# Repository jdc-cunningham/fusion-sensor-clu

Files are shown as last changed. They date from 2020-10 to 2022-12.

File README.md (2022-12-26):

## Update

The second/current version of this approach is [here](https://github.com/jdc-cunningham/pi-zero-2-robot-navigation-head) "Chisel Bot"

## About
This is a piece of crap SLAM from scratch attempt with a Raspberry Pi, camera, ultrasonic/"lidar" sensor on a pan/tilt bed and a 9-axis IMU. Please note I am coming from web-application development so I'm not a SLAM expert or anything, this is just some hobby/fun project for me, don't reference it for anything that matters.

## Completion
- [ ] vision system
  - [x] basics of masking, determining color and light ranges by histograms, determining bounding boxes of largest contour areas
  - [ ] make an algorithm for sampling based on available data ranges and best way to find all objects in an image due to various colors/shapes
  - [ ] get the center of the largest boxes
  - [ ] figure out how to gauge where the object is and then point the sensors at it to get a depth measurement
    - this can be based on camera physical properties but also just sampling with lidar/ultrasonic sensors
- [ ] interface with IMU
  - [ ] connect and get values
  - [ ] estimate position based on rest/accel/velocity
  - [ ] use this to translate points to keep track of where things are
- [ ] add drive servos to body/use external battery separately to drive wheels
- [ ] complete the system where it can be turned on, starts navigating on its own and outputs telemetry to web interface

### Example application
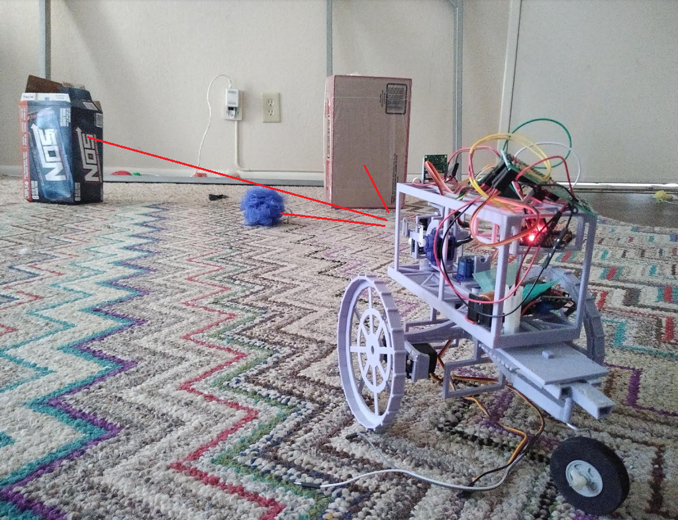
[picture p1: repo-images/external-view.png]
intended vehicle


I am aware that there are methods out there like "visual inertial semantic representation" which are insane! I've seen drone applications with a single camera and it's frame-by-frame attaching dots to things and keeping track of them. No distance measuring like I am. And they pair that with the IMU data to generate depth that's my understanding anyway.

The shot above "why not use an ultrasonic sensor" well they suck on their own. If you're just dealing with perfect walls/no angles then yeah they work great. I'm also aware my approach is probably dumb but this whole project is a learning mechanism for me.

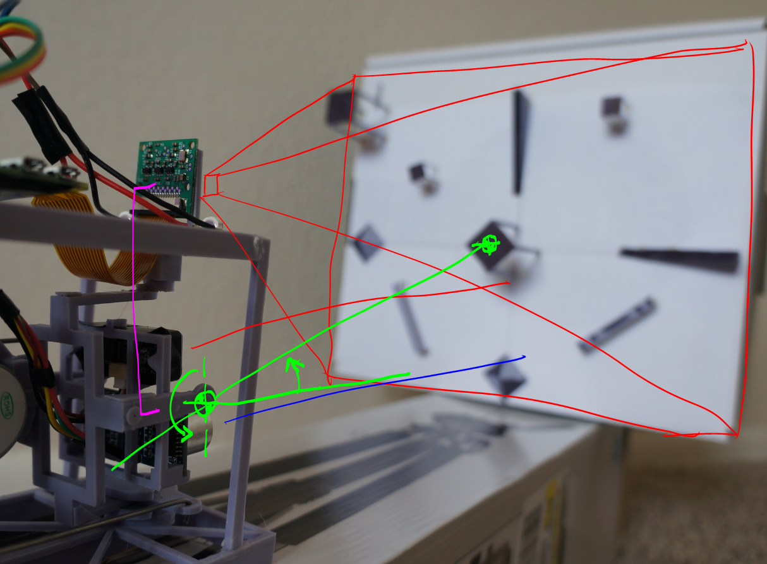
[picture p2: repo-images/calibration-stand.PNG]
initial thoughts


Initially I thought the sensors were way more accurate than they actually are. At the moment I believe the "lidar" at best is for measurements above 2 feet and the ultrasonic sensor is the opposite.

This build is bad in many ways primarily due to the mechanical design/materials and lack of feedback from the pan/tilt sensor bed.

## The stack
- web
  - ReactJS, websocket, ThreeJS
- robot
  - Raspberry Pi
    - NodeJS for server/websocket
    - Python for i2c to Arduino, 3D point cloud/collision
    - OpenCV for visual aspect mainly finding objects, bounding, getting centroid for distance measurement
  - Arduino
    - moves servos for pan tilt by i2c commands
    - moves two 360 deg rotation servos for movement

While I do have a web interface for a visual aspect and manual controls, this robot is intended to operate on its own. The 3D point cloud environment is maintained in memory against the IMU measurements, that's the plan anyway.

### The web interface
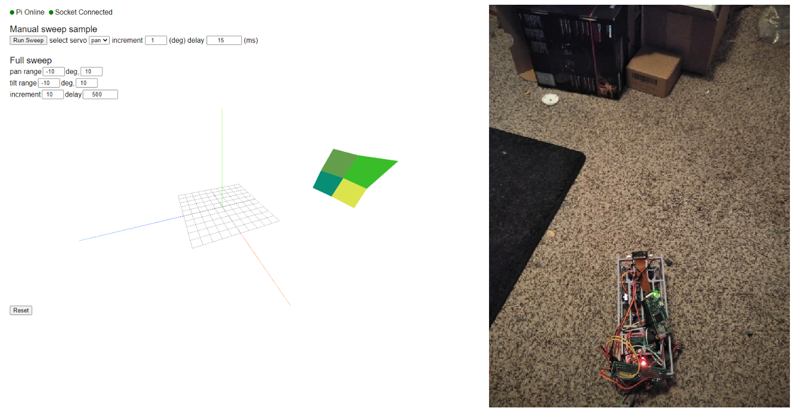
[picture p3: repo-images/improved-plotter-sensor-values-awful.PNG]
showing example 9-point measurement plot


Primarily as mentioned this interface just gives you direct control. Ideally/in the end the ThreeJS part will be almost real time showing the robot's position and the moving environment around it based on what was tracked before. It will all be super dumbed down eg. "everything is a box". One thing I have to figure out as well is mapping the horizon/ground plane.

### The vision aspect

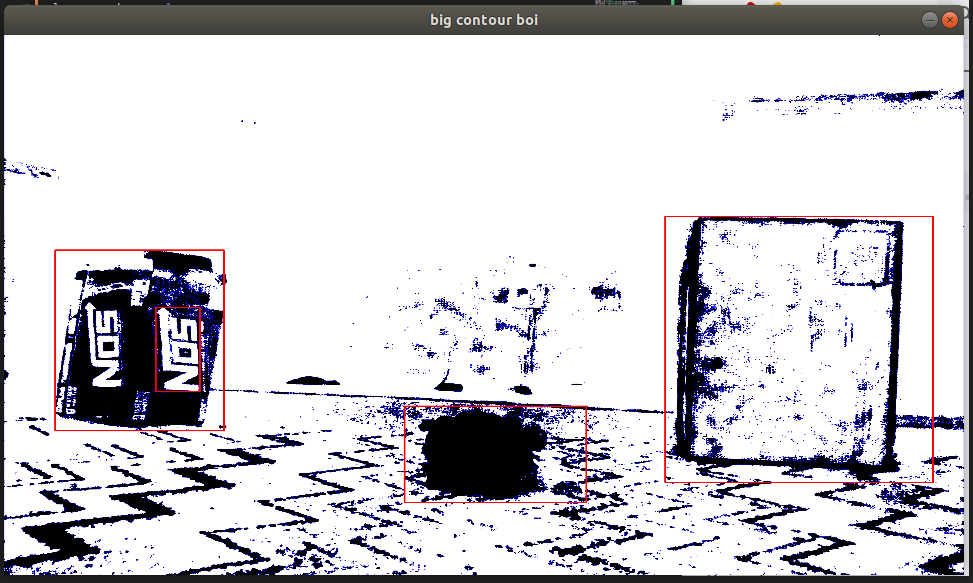
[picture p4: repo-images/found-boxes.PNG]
example masking


This is probably the hardest thing about this project for me followed by the IMU aspect as I have not interfaced with an IMU yet.

The current process is:
* get image
* apply 1D and 2D histograms to get light profile and HS values from image
* use those values for the HSV masks
* find contours by largest area
* get centeroid position of boxes
* determine angles to point sensor bed to get distance
  * maybe involves an initial panning sample with lidar due to angle/fov issue of seen object
* pass these values to the "world coordinate engine" ooh buzzwords

### The maths/IMU
* points are determined for 3D plotting
  * go into ThreeJS for visual
  * go into Python/ram
* IMU values are at center of world, its motions translate the tracked points to simulate reality where objects are/were
* using this and 3D collision detection(box overlap) can tell if you're going to run into something or not
* the known freespace in front determines how far the robot can go before doing something/doing more measurements

### The "main loop"
This is the logic of the robot/why it does what it does. Which is pretty much to keep moving forward if possible. Ultimately the goal of it is to try and map the room. I know I know... just buy a spinning lidar. But That's not the point again not dealing with perfect walls. Also eventually I will take what I've learned here and move onto more powerful boards eg. a Beaglebone or STM32.

### Fantasy/future
* recognition of previously seen objects
  * this one is kind of hard since the objects are all blocks but you could try and average boxes/points and roughly realize these "constellations" haha bs, are some area you've been at before.
* ML for finding the boxes
  * I don't know how feasible, excuse for me to finally try and learn ML for real. I'd have to take so many sample images and annotate them. I had a thought where if the robot fails/runs into something, the last image it has/predictions I could correct(tech parrot).

## Progress

####  11-12-2020
I have written a basic pan/tilt measurement sampling workflow which is then plotted in 3D using ThreeJS. The implementation is basic right now as I have to finish figuring out the math aspect/rendering it correctly.
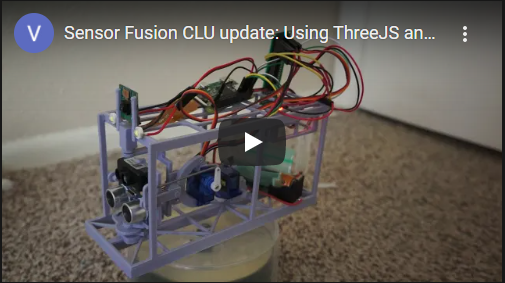
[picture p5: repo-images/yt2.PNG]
youtube video of web interface to threejs (https://www.youtube.com/watch?v=VOdi__m6o3g)


#### 10-28-2020
At this time this project is far from complete. This is also not really meant to be reproduced, it has a lot of flaws.

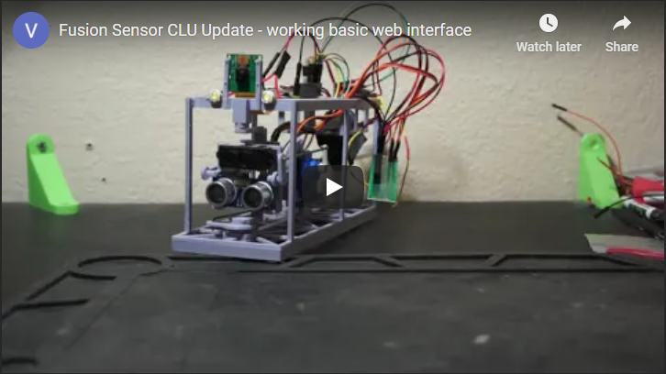
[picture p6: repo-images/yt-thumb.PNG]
youtube video of web interface controlling pan tilt servos (https://www.youtube.com/watch?v=_qi6G4832OI)


It's funny like how much of a piece of crap it looks like and how much work it takes too... printing the top part for example took 7 hrs...

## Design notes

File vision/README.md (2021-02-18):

### About
This is the vision process of this "aparatus". There is a single camera and I'm using 1D and 2D histograms to define the places to look to bind potential objects with HSV. Then using contour finding I find the largest area after a specific minimum area.

It is easier to visually see what I mean by the 1D/2D histograms seeing the images below.

### "The process"

Sorry I'm too lazy to merge these images together right now. This color chart is used as a reference for the purple sample 2D histogram below. I still have to validate manually that this actually works.

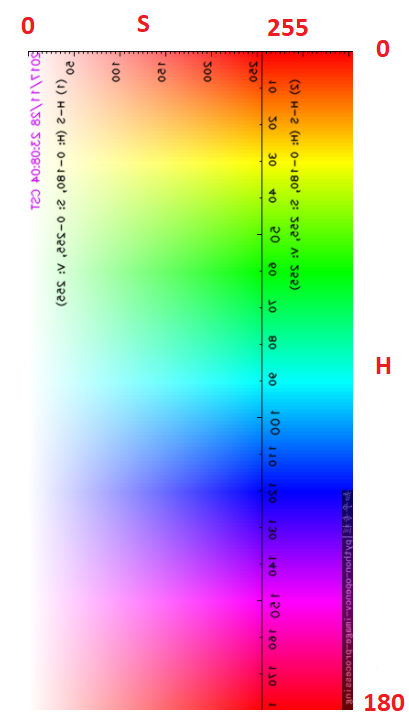
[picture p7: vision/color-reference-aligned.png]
H and S plotted on a chart

This image sourced from here: https://stackoverflow.com/a/48367205/2710227

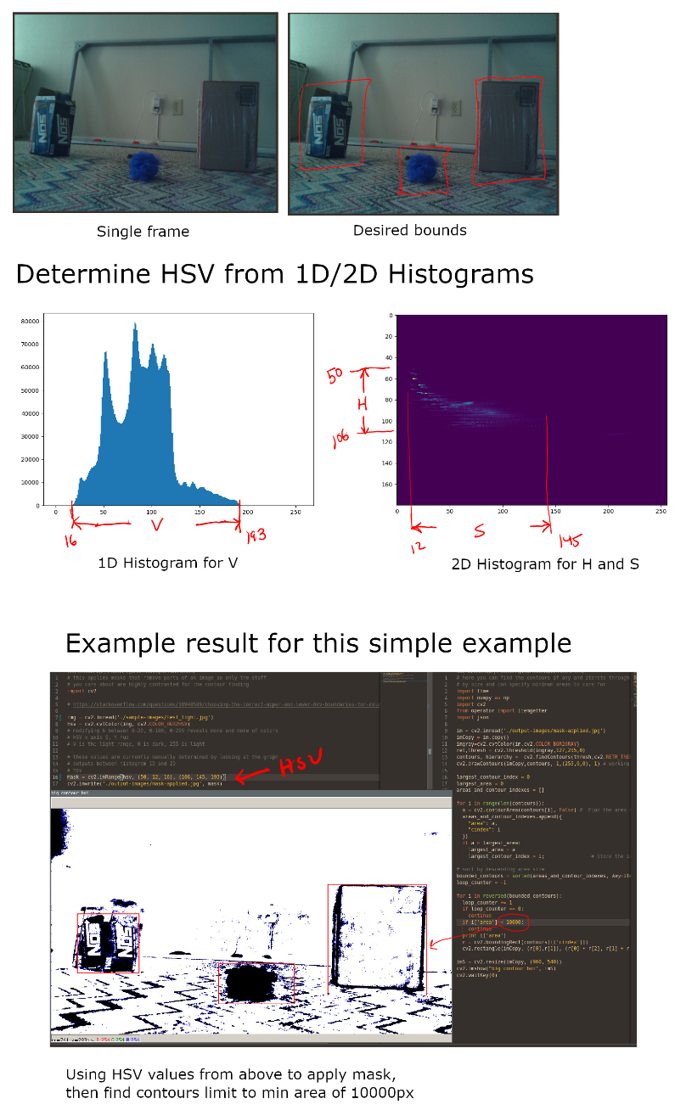
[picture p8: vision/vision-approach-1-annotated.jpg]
vision approach annotated


These bounds are treated as cubes for now/to make it simple. The distances are measured with the ToF sensors and then these values are stored in the "world coordinate system" where the center point(where robot was first turned on) is moved around based on IMU data.

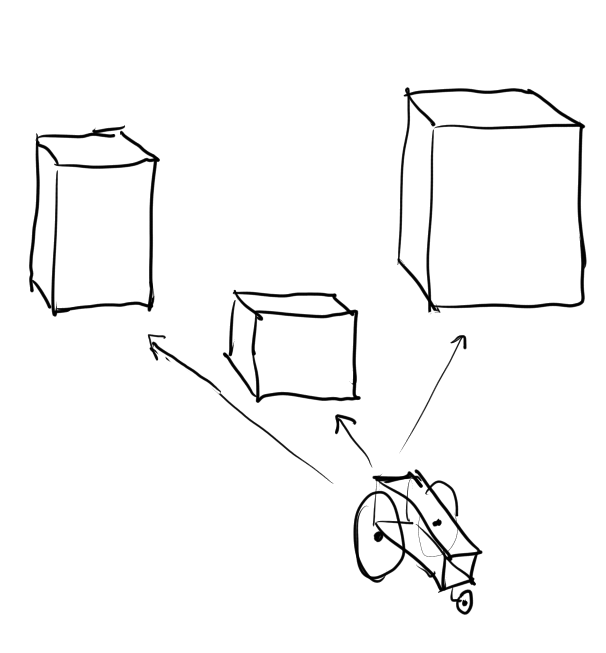
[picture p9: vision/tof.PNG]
approximated 3D objects


I do realize how "lucky"/ideal this simple sample image is. Indeed other images are way harder to draw bounds around, particularly the 2D histogram aspect, that's why I have to step through/sample all the groups. It's also noticeable on the single core Raspberry Pi that can take a process and make it 30 times longer to process due to its processing capability.

### Other notes

Will point out, with the ToF sensors and if it's very dark(V from 1D histogram) can also do preliminary distance sweeps.

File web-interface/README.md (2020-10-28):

# The web interface for the hybrid ground navigation sensor prototype
## This is intended to be used on a touch screen

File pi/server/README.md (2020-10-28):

# the server and socket script should run on boot
## this app uses sysemd based on [Axllent](https://www.axllent.org/docs/nodejs-service-with-systemd/) post

Get both server and socket scripts running so they're visible in process eg. by `htop`

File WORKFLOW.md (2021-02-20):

- [ ] Robot on
- [ ] Turn system logging on(threads/imu)
  - [ ] IMU data sampled by ADC via thread with interrupts
- [ ] Camera takes initial image of environment
  - [ ] OpenCV processing
    - do 2D histogram
    - do contour bounding box and iterate through samples
    - determine box locations
- [ ] do physical samples
  - based on samples above do measurements
  - store/emit
- [ ] Initialize 3D world
  - based on values/points above setup world with robot at center
- [ ] Move/update 3D world
  - do point translation/kinematics/collision detection

end goal is to navigate my entire apartment eg. 5 "rooms" and 1 hallway

### Nice to have features
- [ ] light detection/in relation to 2D HSV histogram
- [ ] basic object recognition after tagging element for updating map "seen it before"
  - particularly since initially will just do lazy approach of "everything is a cube"

### Main tests
- [ ] should be able to tell a wall
  - flat
  - corner
    - away/towards
- [ ] basic boxes
- [ ] complex shapes like a plastic bag

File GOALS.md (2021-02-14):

### These have to be done for it to work
- [ ] Vision
  - [ ] process that can find/draw bounds around everything
  - [ ] ability to target the sensor bed at something and hit it due to the offset from cam/sensor bed center points
- [ ] World coordinate system
  - [ ] store the points
  - [ ] rotate them as the robot moves from IMU data
- [ ] IMU interface
  - [ ] have to get accel, position, rotation, etc... and plug into world coordinate system
  - [ ] determine no longer moving
  - [ ] heading hold regarding servo speed differential
- [ ] Control robot
  - [ ] this should be easy once the above is met, just tells the robot to stop/go/turn

### Future
- [ ] object recognition
  - right now the bounds are basic boxes, but if viewed from other angles should be able to tell it's the same thing seen before

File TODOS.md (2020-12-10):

- ### updates
  - [ ] dpad
    - [ ] add bars/slider
    - [ ] add quick center
    - [x] add setup of major/minor ticks eg. increment by 1 vs. 5
      - only one input but variable
  - [ ] move servo code
    - [ ] add callback when seharvo is done moving, or add matching delay before buttons enabled/able to move again
      - callback from Arduino i2c probably better in case comm delay

- ### reminders
  - socket service user specified is pi to have access to smbus2

- ### "Geometric error"
This is due to the sensors rotating about an offset shared central axis particularly for pitch
Pan has its own problems(since the sensor emit/return are not on the same point/axis)

### Next
- [ ] add background task to Arduino code to unblock itself
- [ ] add reset btn on ui/feed to Arduino
  - happens when some process in Arduino doesn't finish and global variable "something in process"
    left to true
- [x] fix issue with rerender on input after threejs has rendered once
- [x] fix math and update plotting for threejs/add toggles
- [ ] add led lidar
  - test it
  - add as secondary check to confirm measurements
    usensor bad on corners facing away from sensor
- [ ] add method to plot robot as rectangular box in center of ThreeJS plot

### 12/10/2020
Putting a little bit of time in. My brain is not phenomenal I still feel ike a monkey when I can't immediately get some spatial thing. Anyway I took this picture as a reference, shows what the camera can see full resolution. Man idk why this camera sucks but it also wasn't expensive. It's good enough for blob detection.

Also interesting how much of "below the horizon" it sees at the height relative to the floor as a reference

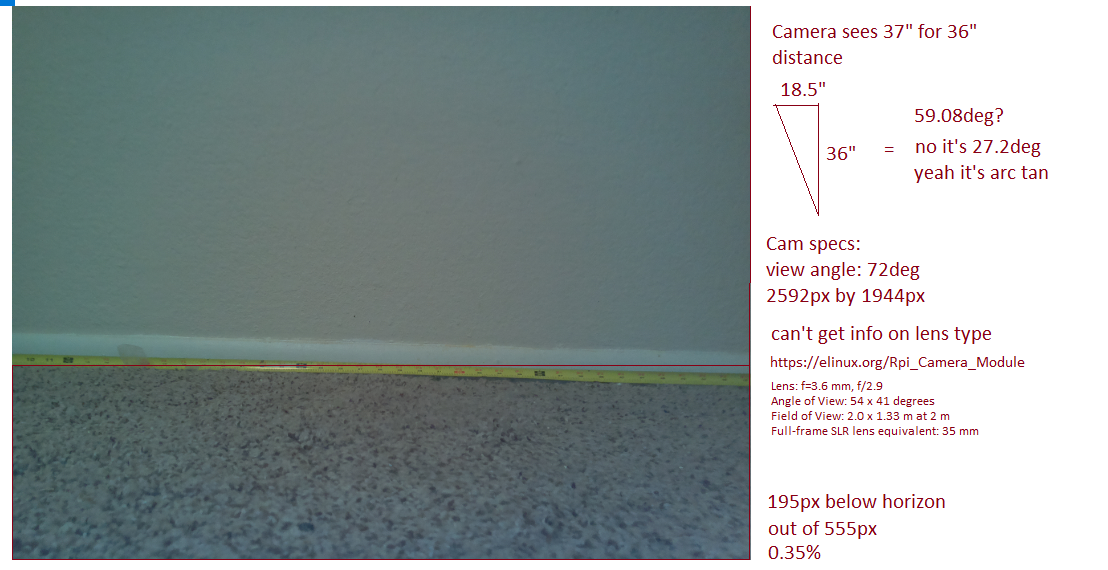
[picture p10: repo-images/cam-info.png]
still don't know


Still don't know yet how to point the sensors at something in picture.
Ugh... my brain sucks. Going to cheat with Sketchup/Cad

For example at 3" the bottom sensor(ultrasonic) has to angle itself 4.5 degrees up to point at the center of the camera frame.

I think aside from general "inference"? Interpretation... idk... I could at the very least do a center sensor sample to get an immediate depth... may suck if something is in front of the object but you could assuming having easy contours use that object as an estimation for everything else based on its bounding box contour size...

There's a relationship though, at least it's a simple right-angle triangle. Half of 36" away it's 9 deg angle up.
The Lidar is a little different, 3.1 deg for 36" and 6.2deg for 18"

Image AR is 1.33 (4/3) or 0.75 (3/4)

Well not scientific at all but can see the camera view angle vs. the sensor angles to point at the same thing due to offset

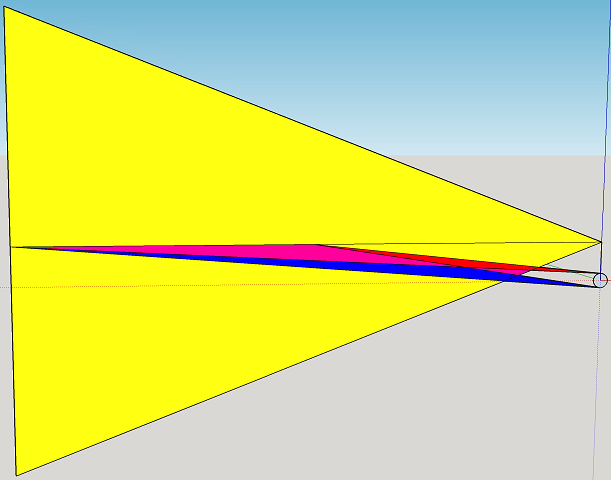
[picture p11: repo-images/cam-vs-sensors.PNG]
sketchup madness


### 12/09/2020
Camera targetting and offset
- [ ] be able to take a picture and based on bounding box/centroid from OpenCV aim lidar/ultrasonic sensor assembly to get distance 
  - example is 4ft foreground(target), everything else is about 7ft away
    - target is 72 square inches

I'm super burnt today, working on this EOD... but today was productive though, a little bit of breathing room.
One of the things I don't understand at the moment is the focal thing of the lens... so if I see something that's 9" across and it is whatever inches on the screen at some pixel... can I roughly know how far awy it is based on that FoV value or whatever.

For now will just work on the basic workflow that will determine the quadrant/point/angles to apply and then use the lidar for the distance ping... if it's closer than the threshold eg. 2' will use ultrasonic for more accurate measurement.

I'm using Gimp to figure out some... well actually paint is fine too. Just need to split the image up into quadarants.

One of the problems is the offset of the camera center with regard to the center of the pan/tilt 

This is the mechanical offset situation... yeah I'm really burnt... can't think anymore. But this is my top priority now personally I want to do a nice writeup/video on this once I have a system that can run on its own.

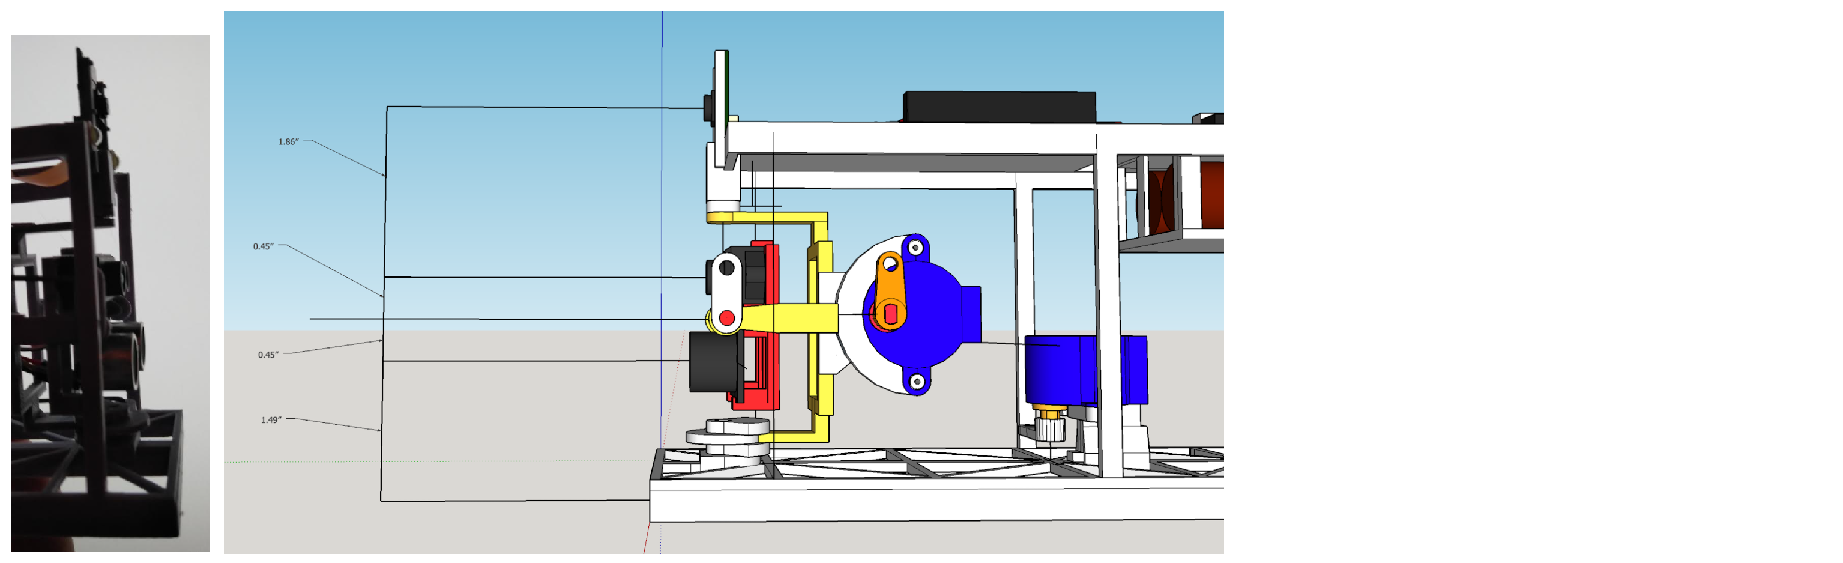
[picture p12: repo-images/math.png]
need to update with math


### 12/08/2020
I did put some time into the panel-splitter-plotter thing(ha). It works now and I added random color to the tiles but the values from the sensor are awful. In particular say facing a corner(with middle closest to cam). It's like measuring infinity or something with the ultrasonic sensor/possibly mismatch of sensor still moving while trying to measure(no feedback).

tears

I did make great progress on the OpenCV part. Some heavy StackOverflowing for that. It's still not written where "it just works" but I have the process down. See this example here where I was able to dynamically figure out the right HSV masks to put bounds around objects in a random picture.

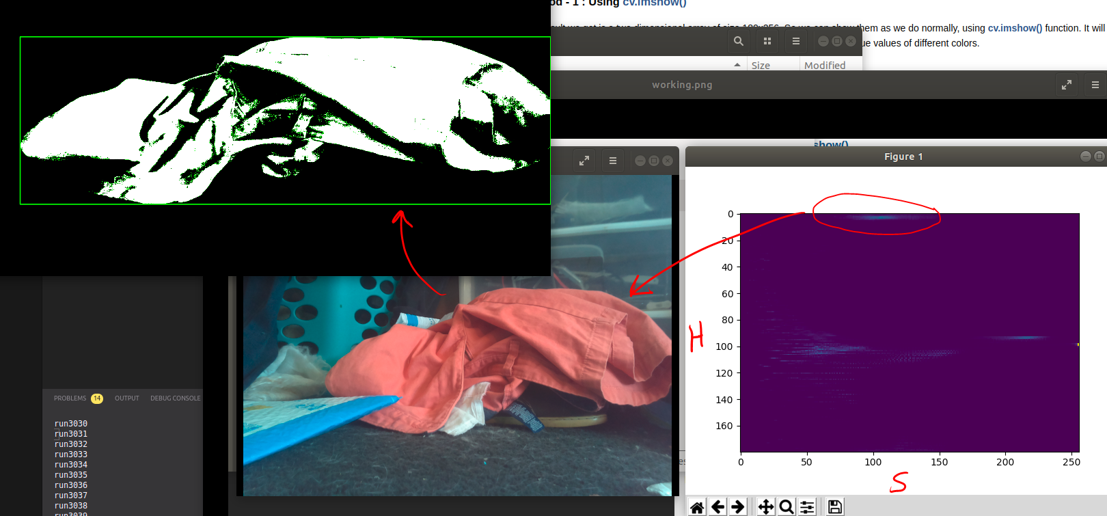
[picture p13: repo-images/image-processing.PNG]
in rain


This project is now top of my list of things to complete though outside of work so I'm hoping to get a write up completed maybe by end of this month December 2020.

I think for the "full workflow prototype" I will just use single-point sampling and treat everything as a box with generous margins of error. Maybe try averaging the "lidar" and ultrasonic sensor measurements.

The IMU aspect is still a big unknown for me at this time.

### 11/26/2020
Well... been busy lately, now have some free time, fresh brain. I had lost interest somewhat, there is still a bit of work to do.

- [x] sweep command stopped working(no change but updated Python cmd string send to Arduino)
  - weird, logged the command ex. `s_p-010,010_t-010,010_i010_500` seems the delay is ignored, sweep sample still works
    not sure if problem is on command part or on Arduino side, no sweep sample is also broken/ignoring the delays
    I will see if reflashing the Arduino code will help(why)
    Oohh look at him, hackerman
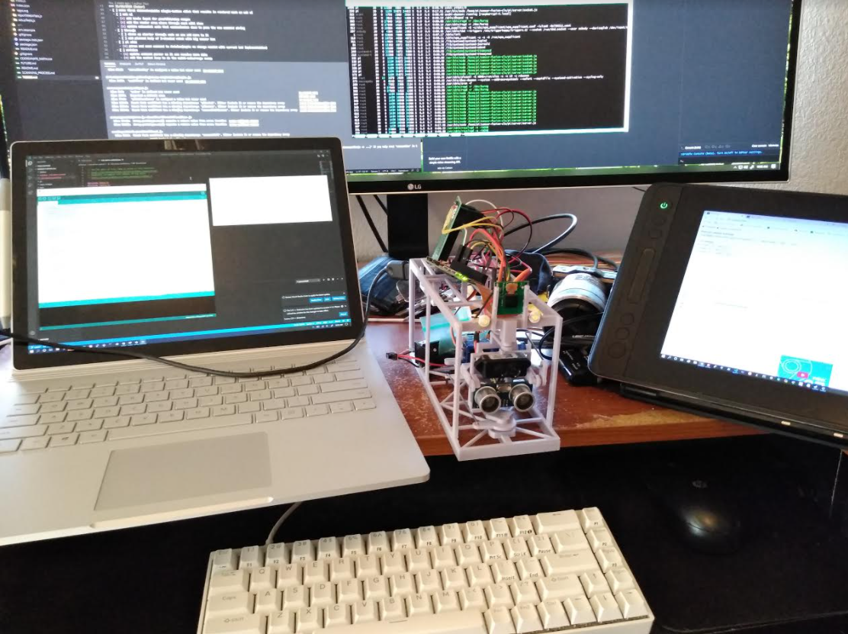
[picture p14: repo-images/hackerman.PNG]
hackerman
    ;
    I do love this giant monitor though, look at me ma! I can SSH
    Anyway I'm adding logging back into the Arduino code to see if it's parsing all the command string characters
    Well it's working again... not sure if the serial print had anything to do with it but the sweep sample while it works has undefined at the end of it... probably a CLI args read issue, but it doesn't seem to affect it so... ugh... I'll fix it. I have to modify either the nodejs code or python code and then reload the systemd service on the Pi.
    Sidenote the Surfacebook is a cumbersome device due to it being top-heavy(tablet is heavier than keyboard). I also have this anxiety about both batteries matching percentages. Still I remember holding one of the first Surface tablets in my hand like 10 years ago... way out of my budget, got this one used. It's cool but I have not really used it yet regarding the tablet aspect.
    so it was literally sending the string "undefined" from node to Arduino... I acknowledge this code is trash
    Anyway I'll remove the serial monitor logs and see if the sweep stuff still works
    One thing I have to do is estimate current consumption, just doing a "started at this voltage, ended with this after x hours", not really sure if that's considered current consumption but I can at least gauge approximate lifespan from 1, 18650 3.4Ah cells.
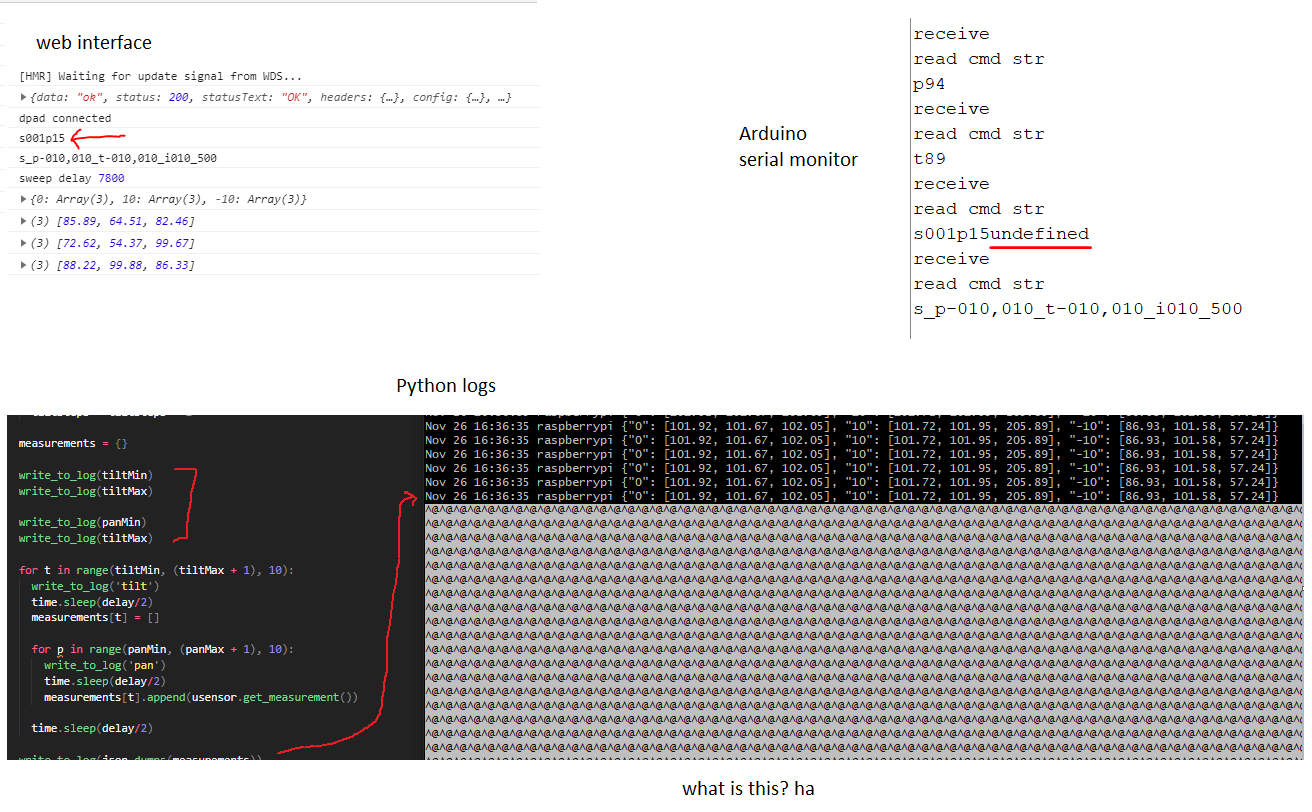
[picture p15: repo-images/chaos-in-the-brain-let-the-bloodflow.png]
madness
    
    sitting "idle"
    3.641V at 11:36 AM
    3.522V at 12:49 PM
    3.301V at 2:13 PM
- [ ] finish function that takes in parameters `(distance, sweep, tilt, increment)` and returns the coordinate pairs for the vertices to make the "plane" or polygon
  - pan pattern starts top left then goes to top-right
  - [when your meager brain cells collect into a pool and somehow establish thought](https://www.youtube.com/watch?v=ZeFonavUHTg)
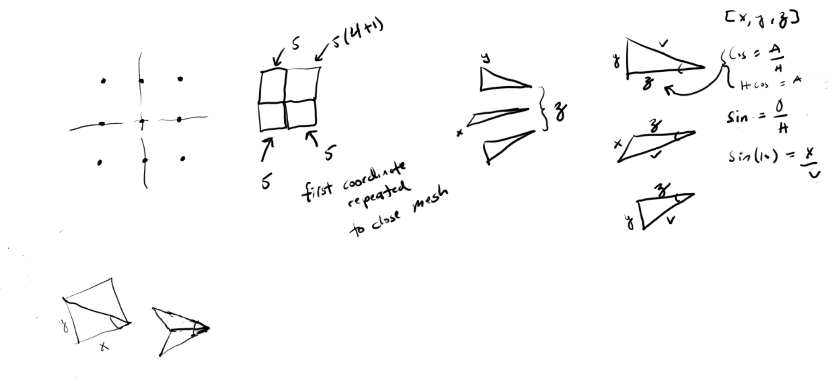
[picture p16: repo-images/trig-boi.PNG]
basic trig
  
  I prototyped out the code to generate the points but  I'm still missing the groupings to generate the mesh/planes
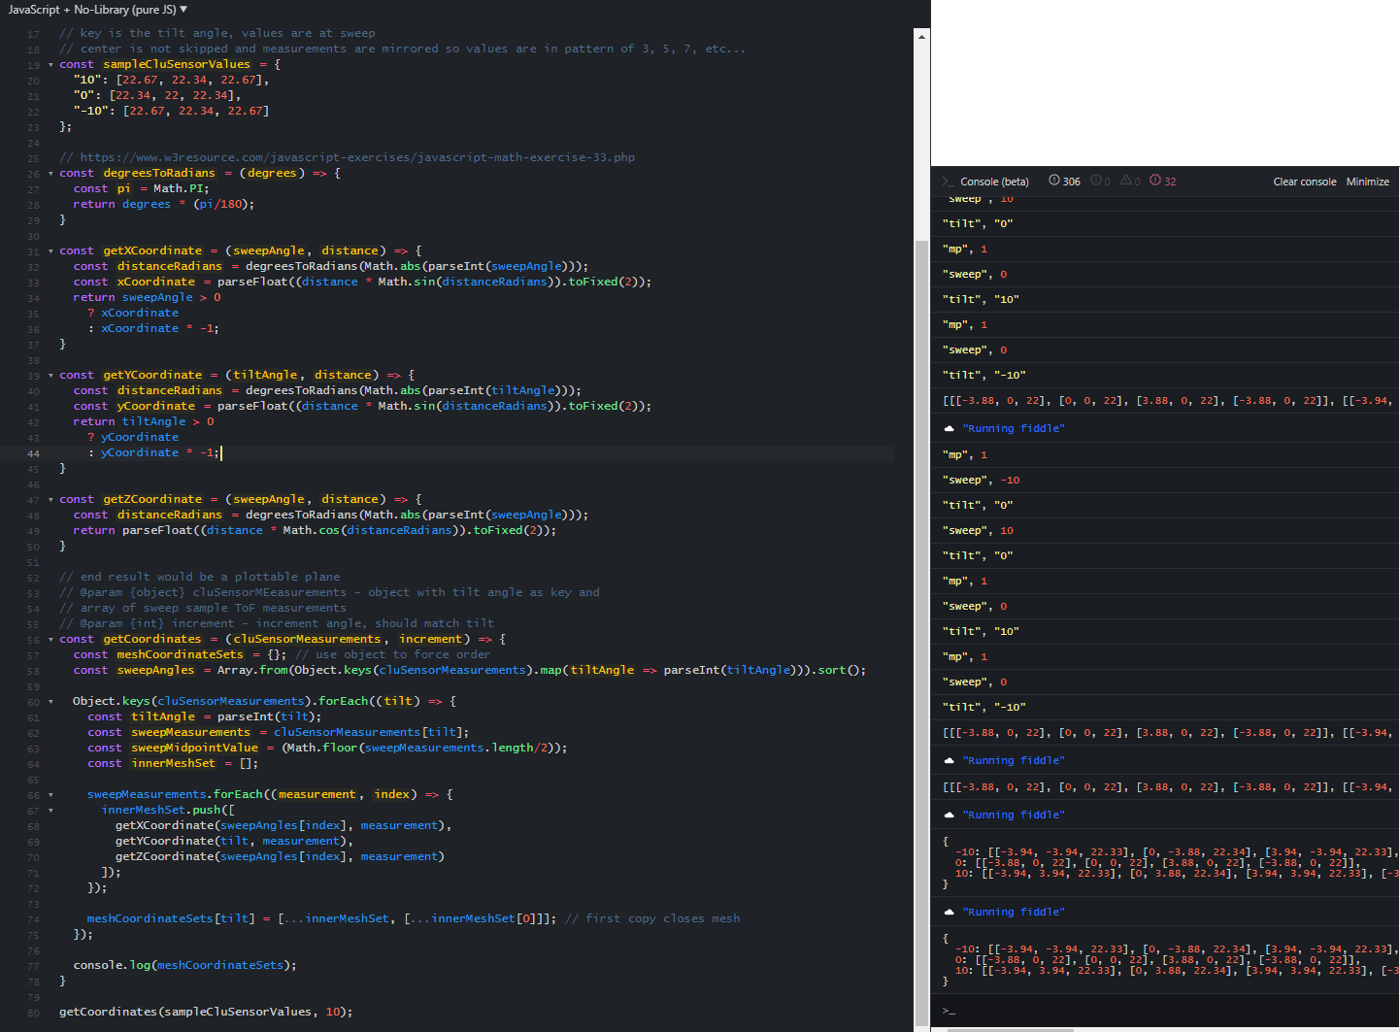
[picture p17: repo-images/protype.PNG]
proto-scopo
  
  seems I have to reset the Arduino if the delays are ignored...
- [ ] start on OpenCV side that scans an image for color groups and then aims the sensor in those directions to get a sample... perhaps can find the corners in a simple case and create approximations(planes) at the appropriate distances
  - so many of the OpenCV tutorials online literally just code out what are in the docs... it's like "we're going to find the red cup" wow! Amazing... every freaking video man.
    it's like, no, I need to be able to find a dynamic range of unknown colors, how do I do that?
    It will be cool when I reach my goal about the "real time running world coordinate system" (bs) regarding the known world position of the robot based on IMU values, stored 3d point objects not only for ThreeJS visual but the mirror that's running in Python for the robot's navigation, ThreeJS is just a human visualization thing.
    I've never built something like this before so it's cool if I get something that remotely works, I realize it's trash and not real time like waving around an iPad in a room to generate a 3D mesh/point cloud collection but still... if it can navigate a robot that's the main goal
- [ ] add "connecting..." ajax spinner to status indicators
- [ ] fix the reset/remove ThreeJS canvas issue

### 11/10/2020 (later)
- [ ] make first demonstratable single-button click that results in rendered mesh on web ui
  - [ ] web ui
    - [x] add basic input for pan/tilt/step ranges
    - [x] add the render area where threejs mesh will show
    - [x] update websocket code that communicates down to pass the new command string
  - [ ] threejs
    - [ ] clean up starter threejs code so can add more to it
    - [ ] add planned body of 2-wheeled robot with big sensor box
  - [ ] pi side
    - [x] parse and send command to Arduino(maybe no change needed with current bad implementation)
  - [ ] arduino
    - [x] update command parser so it can receive more data
    - [x] add the nested loop to do the multi-axis/range sweep

### 11/10/2020
This todo list has become more of an insanity log. An update from before, I initially was trying to learn WebGL but thankfully I found the path of Threejs.
After doing the panic Google session and countless threejs examples/stackoverflow questions I have formulated the basis for the visual rendering.
Earlier(few days back) I wrote the basic math functions to take the measurements coupled with the pan/tilt angles to generate the 3d coordinates... which also need to get cleaned up still.
Anyway I am at the point now where I can make a visual representation of it in 3D to be displayed on the web.
It's not part of the navigational system that will be all in memory but it is a nice-to-have thing. To map the world/gather data and update it based on kinematics(onboard imu).
Mostly I needed a quick burst of "I'm not a failure" even if it's a fantasy/joke what I'm working on.

I'm working with the sample coordinates mentioned below. I still have to investigate why 20+ deg tilt is ignored/cancelled... probably some dumb code in Arduino that I wrote.

I can't spend too much time just wanted to visually display the points below in 3D space using Threejs.

Well... this is not correct at all since I had to throw away a lot of the values and I think the mesh drawer that makes this 3d shape just joins stuff.
If you're looking at this it's not even correct, the point(corner of wall) should face the camera.

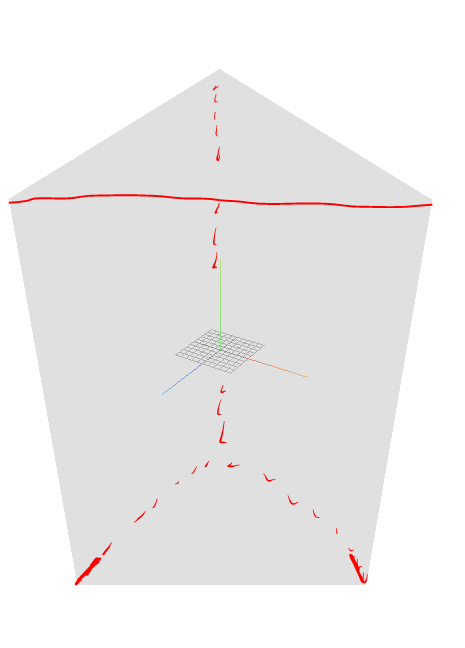
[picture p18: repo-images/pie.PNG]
something


Anyway it's a a start(ain't much meme)

### 11/05/2020
- [x] look into why the angles don't match
  - due to mismatch horn lengths and the horns weren't parallel to each other from the start, only affected pan 
  - updated horn(extended) and updated center points
- [ ] try simpler set of points, see if can plot a plane
- [ ] read through webgl example code
- [ ] full functionality eg. from web command to scan/display webgl "meshes"
  - determine the string command for box scanning
  - do full math
  - add other "callback" part on front end that runs after certain time has passed(dumb) depends on number of points
  - pull the values hosted by pi server
  - plot in webgl
  - then start doing the world mapping
  - add imu
  - add tracking
  - add collision detection
  - add OpenCV blob finding and combine that with above for determining what to scan and plot in world
  - add coordinate find from image and factor in offset based on camera overhead position and pivot point of sensors, general accuracy errors
  - collect data
    - corner wall at 45 degrees, 2ft away
    - us
      - 20 - won't sweep
      - 15 - won't sweep... will have to investigate Arduino code, watch serial
      - 10 - [39.86, 33.91, 34.12, 33.91, 33.87, 34.11, 34.25, 34.59, 34.47, 35.24, 35.68, 39.99, 41.19]
      - 0 - [24.38, 34.18, 33.98, 34.19, 33.99, 34.29, 34.15, 34.35, 34.66, 34.89, 39.42, 39.49, 39.63]
      - 10 - [35.44, 34.29, 34.07, 34.45, 34.08, 34.25, 34.25, 34.35, 34.81, 35.79, 39.71, 40.01, 39.86]
      - 20 - [40.24, 34.72, 34.97, 34.5, 34.84, 34.99, 34.71, 34.82, 35.44, 39.61, 40.73, 40.45, 41.13]
    - lidar - measurement stuck at 65533, not sure if broken or battery
      - it was the battery, after putting in a fresh cell at 4V, was working again, it's bad as I mentioned around 2ft but I measured 38" and it was off by about 0.5"
        vs. 2.5" or so when measuring 18" but received 20.5" as a measurement
      - 20
      - 10
      - 0
      - 10
      - 20

### 11/04/2020
- trying to actually get something done today
- [x] test angles see accuracy and if measurements still work
  - [x] verify angles visually
      - this is not very accurate at all, the accuracy magnitude I had planned initially is way off at least for the "lidar"
  - [x] check measurements from ultrasonic sensor
    - usensor face is 0.5" off (less) from pan/tilt axes, also seems like camera face is 3/8" back from us sensor face
    - yeah this thing is unfortunately f'd since the part where the beam/wave leaves the sensors are not directly in line, there are offsets
      especially when it rotates about the wrong axis
    - rotate 10 deg right, measured 17.73" + 0.5" => 18.51" compared to expected trig value: 18.28" -> 0.23" margin of error
      try again
      10deg -> 18.23" expected, actual is 17.51" + 0.5" -> 18.01" -> 0.22" error
      20deg -> 19.16" expected, actual is 17.72" + 0.5" -> 18.22" -> 1.44" error oof
      30deg -> 20.79" expected, actual is 18.1" + 0.5" -> 18.6" -> 2.19" error ahhh
    - try lidar at 2' -> measures 26.38" -> now bang on at 61cm or 24.02"
      10 deg -> 65.5 cm (avg) -> 66cm
      20 deg -> 66 cm -> 97cm on second measure going backwards
      30 deg -> 78 cm -> 
      ehh... idk... also able to pan farther out than "limits" eg. max of 30 deg in either direction, maybe a good thing (60deg not a big fov for sensors)
    TLDR these measurements suck/not reliable, a panning/general averaging may be passable given enough large margin of errors
    Also sometimes the servos don't move... even when commands are sent, that sucks, concerning
- [x] write first sweep samples
  - ex of 5 deg incr, within 60 deg limit = 12 points -> 6 seconds duration, tested and took about 7.86 seconds to start and stop moving(recenter at end of sweep)
    - as simple baseline can sample at half the speed of delay eg. 500ms = sample every 250ms
    stuck on file writing issue
    - this is not great but I'm just creating a folder with 777 permission, inside that a file with 777 permission
      this code runs by systemd and the user is set to pi, logs confirm as pi but for some reason denied to write to file still when node calls python cli exec cmd
      setting working directory in service that runs the socket
      hmm hmm hmm... this is bad... can't get anything to write
      so... 3 hrs later and crying blood... I guess somehow the python file is cached that node calls, since I disabled the bus write line but somehow the servos
      still respond to the web ui calls
      Jesus... lmao I didn't change the new directory for this project in the socket part of nodejs so it was never calling the updated python file... ahhhhhhhhh it's fine... we all age
- [ ] come up with box-sweep string cmd
  - has to be simple defined by end limits and steps(vertical samples)
  - ex. current sweep cmd s001p500 -> sweep, 1 deg, pan, 500
  - Arduino can only understand code like above so far so python has to do the parsing/bus calls per delay
  - I think for now I will get manual coordinates then I will plot them into webgl
  - I'm doing new measurements again and it doesn't seem too bad actually the values
  - manual measurements, 7 rows (30, 20, 10, 0, -10, -20, -30)
    - what's interesting is the 0 plane referencing which sensor/around which rotation point... I tried to do that in this design but I messed it up since I didn't know where the waves propagate from
    - these values have to get cleaned up (outliers)
    [
      [17.62, 36.23, 58.89, 44.22, 59.2, 58.88, 54.89, 17.99, 18.13, 17.65, 18.2, 17.78, 18.01], // 30
      [17.5, 18.11, 17.7, 17.89, 17.52, 17.36, 17.39, 17.52, 17.58, 17.41, 17.33, 17.33, 17.55], // 20
      [17.39, 17.39, 17.57, 17.8, 17.45, 17.6, 17.2, 17.39, 17.22, 17.22, 17.05, 17.39, 17.35], // 10 deg
      [17.31, 17.67, 17.51, 17.54, 17.47, 17.38, 18.28, 17.26, 17.31, 17.33, 17.33, 17.45, 17.27], // 0 deg
      [17.46, 17.98, 17.91, 17.76, 17.6, 17.6, 17.6, 17.76, 17.62, 17.58, 17.39, 17.42, 17.63],
      [17.85, 18.06, 18.16, 18.39, 18.16, 18.0, 18.18, 18.07, 17.99, 17.87, 17.86, 17.86, 18.03],
      [19.15, 133.03, 132.53, 132.63, 132.7, 20.73, 20.06, 19.08, 19.01, 18.82, 18.75, 18.83, 18.84] // this angle too steep until mounted to frame
    ]
- [x] write trig math to get x, y, z coordinates
- [ ] maybe plot coordinates into webgl even if manually done
    - it just occurred to me that the points had to be connected to have faces... I just had dots
    so I tried a 3d scatter plot and I think my math isn't correct or how I mirrored the values isn't right.

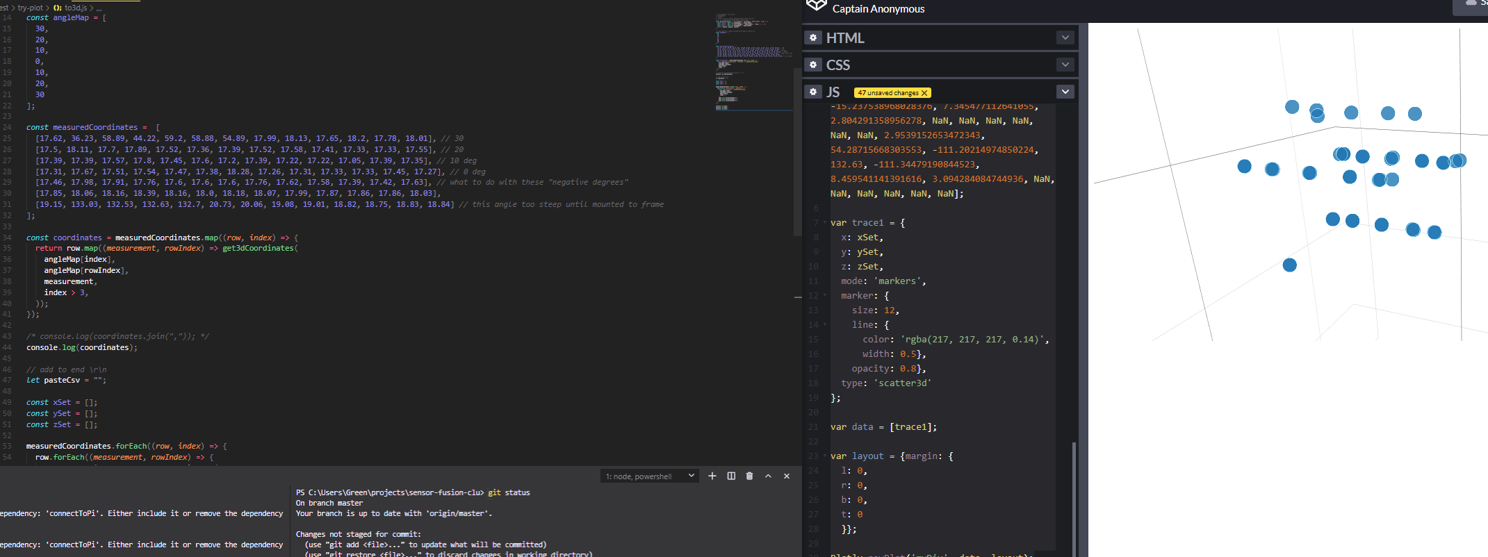
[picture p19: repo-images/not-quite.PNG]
try plot with plotly3d js
    

    What I was trying to measure(the headphone box at 17.25" away from us face)
    
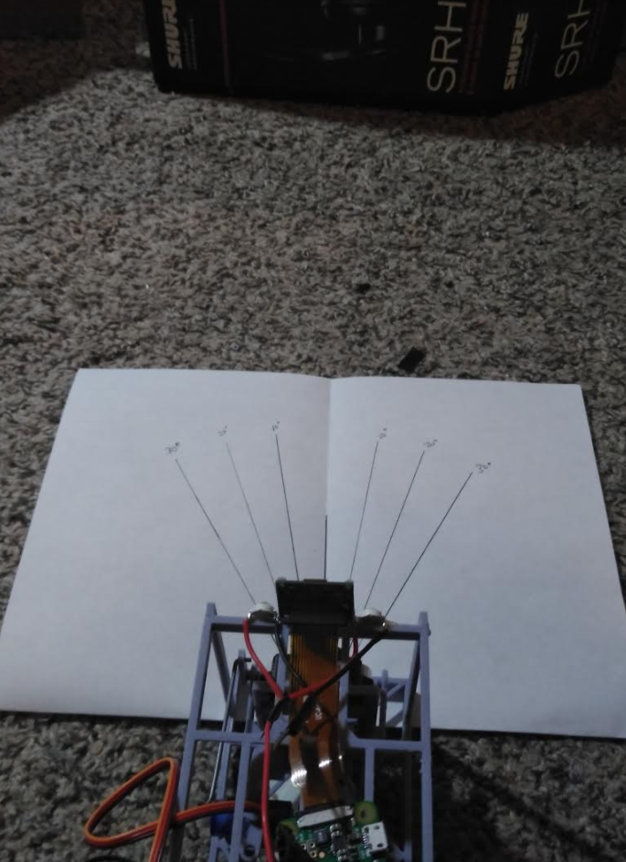
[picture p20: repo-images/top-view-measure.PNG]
top view measure
    

    What the camera's seeing

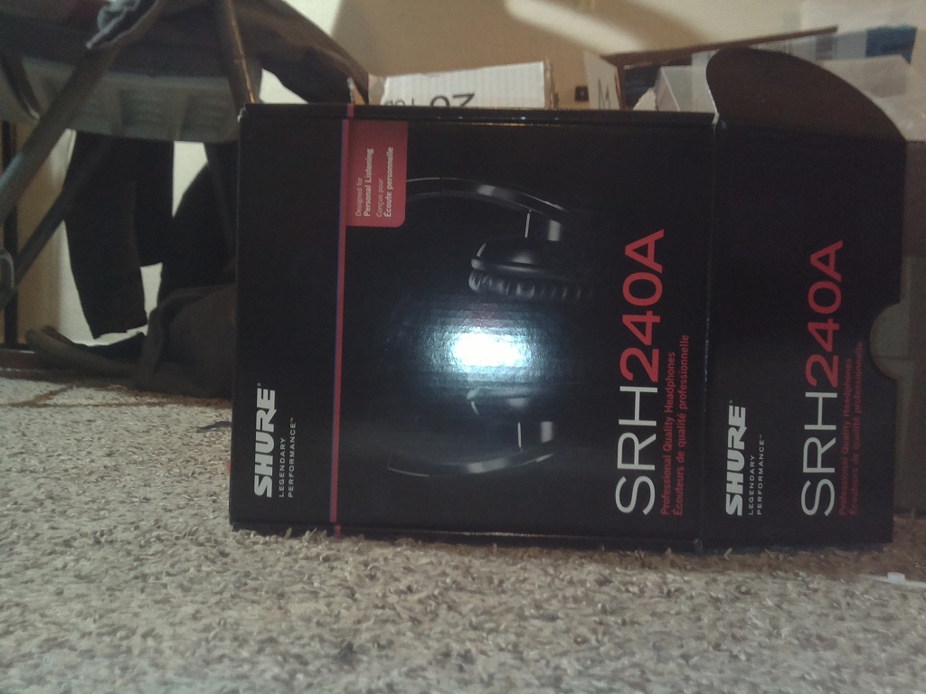
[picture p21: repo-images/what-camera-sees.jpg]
camera sees
    

    I also realized my angles don't match eg. 3 x 10 deg increments doesn't go to 30 degrees (paper). Ooh... it's probably my servo arm length not matching the horn on the other side.

### 11/03/2020
- I think I may have a self-sustaining drive to finish this project now, where I will, "will" it into existence
  even if it's a piece of crap
- I'm thinking about how the scanner will work
  "brought to you by X1 Carbon 3rd gen" ha always wanted this laptop though I hate the left-most fn key
- scanning process, Arduino is still disconnected from Pi/Python in real time due to i2c interrupt being brief/prefer batching
  also ultimately any sort of "position/is-it-done" kind of stuff with a servo is pointless without a measurement eg. ADC on Pi side measuring spikes on servo by pot hack or something
  eg. quit using crayons and get a motor with an encoder or something
  - websocket sends command to sweep(x,y)
  - python code that talks to i2c to send simple string command sends command but also starts python sensor measurement gathering
    - all under pretense 1 second apart delays per servo motion or whatever delay sent down by websocket is honored(flaw)
  - the data is just stored, no math is performed
  - after the scan the math is performed to get the x,y,z coordinates for the 3d plotting from angle/arcs
  - these values will get read however the process is initiated from front end as part of parent event(sucks because socket is using node then talking to python)
    - some kind of bus between node/pyton I think is possible too, right now I'm using `exec` which is one directional in a full linux board at some point, the type that has mixed my use case
    - not impossible to use python socket but a PITA and having to mix python versions(also not impossible)
  - values received by webgl plotter on front end, then I can visualize it, ooh pretty the skewed piece of crap
  - next would be some world modeling/translation based on motion(IMU interface/attached to wheels)
- at some point will actually use OpenCV as the main driver
  - takes image
  - scans image for objects
  - do process above however with override to not sweep but pick specific points to probe or partially sweep
  - all based on the pan/tilt, camera fov, etc... in other words probably will suck, but once I have a full system can improve upon it
- I think I will use something like a Beaglebone in the future, try to keep the "language" a single stack, except for the web part, may go for desktop just for experience/learning
- added a `SCANNING_PROCESS.md` and `FUTURE.md`

### 11/02/2020
- crash course in lobotomy
- time to perform my magic trick of making a rock absorb blood
  - super burnt
- [x] going to try a boosted single cell battery for the first time
  - damn I soldered first one backwards in polarity, magic smoke... glad I have several
  - working now pretty cool first 18650 cell this one is 3.4Ah
- [x] add real time increment input to adjust
- [x] will determine max pan/tilt ranges
- [x] add wrapper to servo calls in Arduino that checks against max pos
  - printing out write degrees is a good idea before actually talkign to servos turns out
    - sent in 5557 (deg) haha
- [ ] create first polling/measurement set that runs from web all the way down
- [ ] plot 3d points in webgl (may be tough have watched some videos, skimmed MDN tutorial)
- at this time I am super burnt so we'll see, I won't give up till I'm crying or something happens
- crap did a download for VS Code/suggested after opening ino file and now touchpad/keyboard doesn't work ha
- this thing is trash in the long run, does not reposition, no position callback(encoder), cross language calls... ehh
- hit a wall delay in dynamic loop is ignored so sweep doesn't work
- guhh still stuck, monkey brain me trying to pry the end of a battery, so it starts smoking/getting warm as the walls are crushed/making contact. I got lucky it didn't get worst, but I commemorate this project to the 18650 which I had to drain, send back to the underverse.
- wow... that was a time sync... dumb dumb dumb. So you're not supposed to call delay and serial and shit inside a handler for i2c... I think shared clocks or something... anyway I have to refactor my code then I am closer to getting the 3d coordinates and plotting them in webgl. After that bridging OpenCV as the primary "brain/driver" in conjunction with the physical measurements to generate essentially a slower/more piece of crap real time map from an RGBD camera... but... it's on a Pi Zero(kinda).
- so I kinda failed... I know what I have to do, have to rework the code so the events are flags, will look at [this i2c guide](https://forum.arduino.cc/index.php?topic=683181) so I can get data back from Arduino on demand if I need to

### 11/01/2020
- [x] try out node i2c
  - see if it works
    - stop systemd code
    - try node i2c examples, check serial monitor
      - had to add new lines to stuff
      - doesn't work... write runs, Arduino receives nothing, error callback happens but says null
      - did have problems with the gcc install stuff(paths/package don't exist)
  - try to use it with websocket so Arduino response goes back up to web interface
- [ ] other alternatives
  - get websocket to work in Python, issue is Python version mixing
- well... I think I'm done with messing around with that, I still have not gotten the hard part, there may be a minor disconnect between servo motion and reading sensor data but I can just do batch sweeping/waiting/assumptions. I still need to get to the actual hard parts of this project eg. the basic 3d mapping from image/physical sensor data sampling
- thought about using a "signal" wire for events, it would be get a start/end pulse from Arduino and read by the pi through ADC, but it would introduce a lot of complexity.
  - main reason may not be worth it is the servos don't have tracking so can only assume they're done moving
  - still having an end signal come from Arduino is something
- [ ] get panning points
  - add pan code
  - do intermittent sampling, issue is syncing commands between Arduino and Python without a bridge

### 10/29/2020
- ### web interface
  - [ ] get feedback from Arduino after servos move
    - just echoes back command, front end uses to decide if next commands can go
    - just occurred to me, I need to be continuously listening to the Pi i2c to get anything back from the Arduino
    - which more than likely means some kind of thread and regarding communication between websocket/web interface...
      - probably have to write the socket in python instead vs. node, then the i2c listener thread can be started and ping the websocket that's running in python
      - no need to figure out how to communicate between python/node in real  time
      - so... when reading i2c the servos twitch... looks like it's a known problem, had a thought. I can just read out variables stored in Arduino by calling it(down send i2c)
    
  - [ ] trigger camera and display photo
  - [ ] get measurements from us and lidar by button click

### 10/27/2020
- ### web interface
  - [x] basic layout
  - [x] add basic servo control input
      - arrows and display of value
  - [x] add pi online status
      - [x] make this not hardcoded, possibly scannable by front end
  - [x] add websocket connected status
- ### pi
  - [x] setup basic node websocket
  - [x] send controls to arduino by system calls to python scripts
- ### arduino
  - [x] make basic servo state manager
  - [x] add accept capability to command servo from i2c and set state

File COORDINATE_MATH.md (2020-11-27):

### Pan/tilt sampling

I've been stuck on this for a while just because it doesn't look right on ThreeJS.
Maybe I'm getting the right values but I'm not plotting them in the right order.
I should be seeing a plane which I have plotted before with test coordinates.

I'm cheating with 3D modeling vs. raw math to visually view stuff/get coordinates.

This is a visual example of a 10 deg sample at [10, 0, -10] tilt samples with [10, 0, -10] deg pan samples per tilt angle.

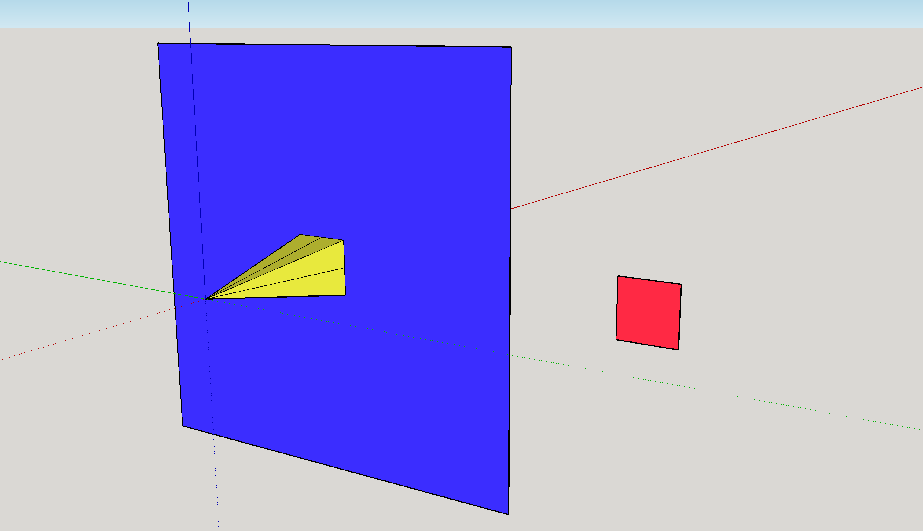
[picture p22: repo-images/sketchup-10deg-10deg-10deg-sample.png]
sketchup mock of 10 deg pan tilt sample


The red is the plane that should get plotted in ThreeJS.

Each vertice of the polygon is an ultrasonic/lidar sample distance. The vertice length for each side of the "pyramid" is 22.67" which the center one is 22"

I have written math for this already/prototyped it in JS fiddle. It's a mix of sine/cosine.

This is the set of coordinates grabbed from sketchup that my function should generate.

Coordinate system is [x, y, z] z being red axis in image

Units in inches(sorry metric people)

```
[-3.88, 3.88, 0], [0, 3.88, 0], [3.88, 3.88, 0]
[-3.88, 0, 0], [0, 0, 0], [3.88, 0, 0]
[-3.88, -3.88, 0], [0, -3.88, 0], [3.88, -3.88, 0]
```

plotted from point of measurement (switch 0 with 22)

```
[-3.88, 3.88, 22], [0, 3.88, 22], [3.88, 3.88, 22]
[-3.88, 0, 22], [0, 0, 22], [3.88, 0, 22]
[-3.88, -3.88, 22], [0, -3.88, 22], [3.88, -3.88, 22]
```

function is of the form `function getCoordinates(distance, sweep, tilt)`

I've got a song on loop blasting down my ears and heavy caffeine, like forced programming at Guantanamo or something.
Arguably less productive than silence when not performing rote coding.
When I need to focus I'll usually loop some song over and over like an insane person

Alright I'll concede need silence for this... figuring out this coordinate calculator thing
I had an epiphany while getting some water... the full sweep is mirrored so x * y = whatever number squared eg. 3 = 9 points
... I don't have to figure out the sweep angles based on number of measurements, I'll just use the tilt angles that are being used as the measurement keys
Referring to the current JSFiddle version [here](https://jsfiddle.net/ys6hzbk4/21/)

I like to prototype snippets of code in a sandbox like this
Awe how cute, he's struggling with basic trig... WolframAlpha is great, had to convert from degrees to radians for `Math.sin` to work right

Having problems again with full sweep ignoring delays

Ughh... I did this wrong. I'm just connecting rows of dots not the four corners of a square, I'm missing some steps

Groupoo

I'm not great at math so this is a struggle... how do you slice a matrix into quadrants by nearby four points?

What happens if I just plot all these points as is?

Oh man... I'm lucky joins the planes for you... need an irregular shape sample though to confirm

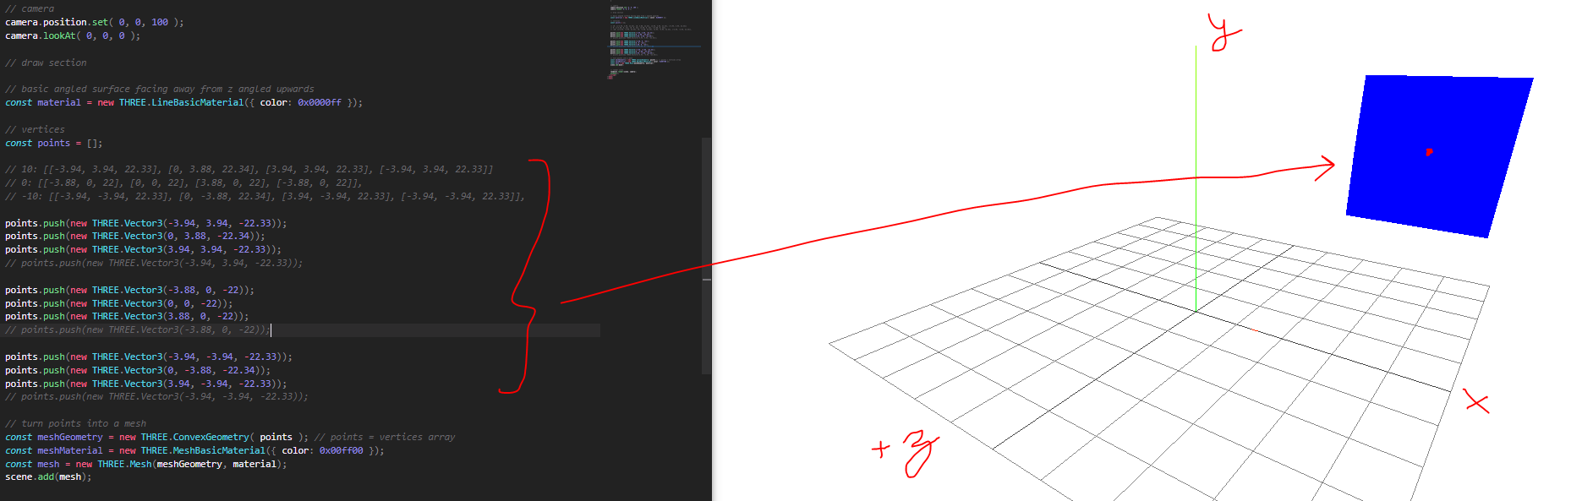
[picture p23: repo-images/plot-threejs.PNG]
plotty-boi


I just realized I may be underpowering the Arduino since the power is setup as a Y-feed from the step up converter. I measured the Vin rails of the Arduino and it's only 4.9V from the 5V source shared by the Pi... docs say it's supposed to be 7-12V hmm... wondering if that's related to the ureliable timer.

I may have to rework this. Something ugly like step up to 7V, parallel feed to Arduino Vin and linear regulator down to 5V to Pi... ehh that sucks.
Ahh.. something's wrong that I'm not aware of(obvious as to why). I tried both a linear regular and a step down... have problems.
Either Pi can't boot(linear) or the step down is having problems.

Yeah that was pointless... waste of soldering time/prototype solderable breadboard space
I just went back to what I had before but plugged into the 5V pin on the Arduino vs. the Vin

So... ate some food, roughly 7 hours later from start today
It is a bad idea to just depend on that mesh "averaging" or whatever happens when you don't exactly specify what to plot. So I think I will have to come up with that math that divides the ranges into "quadrants" to plot.

It may be placebo but it seems like the Arduino is working better.

See the examples here where you can't really tell(since everything is blue and not based on "2d planes") what this is, at least the distance makes sense from the center axes

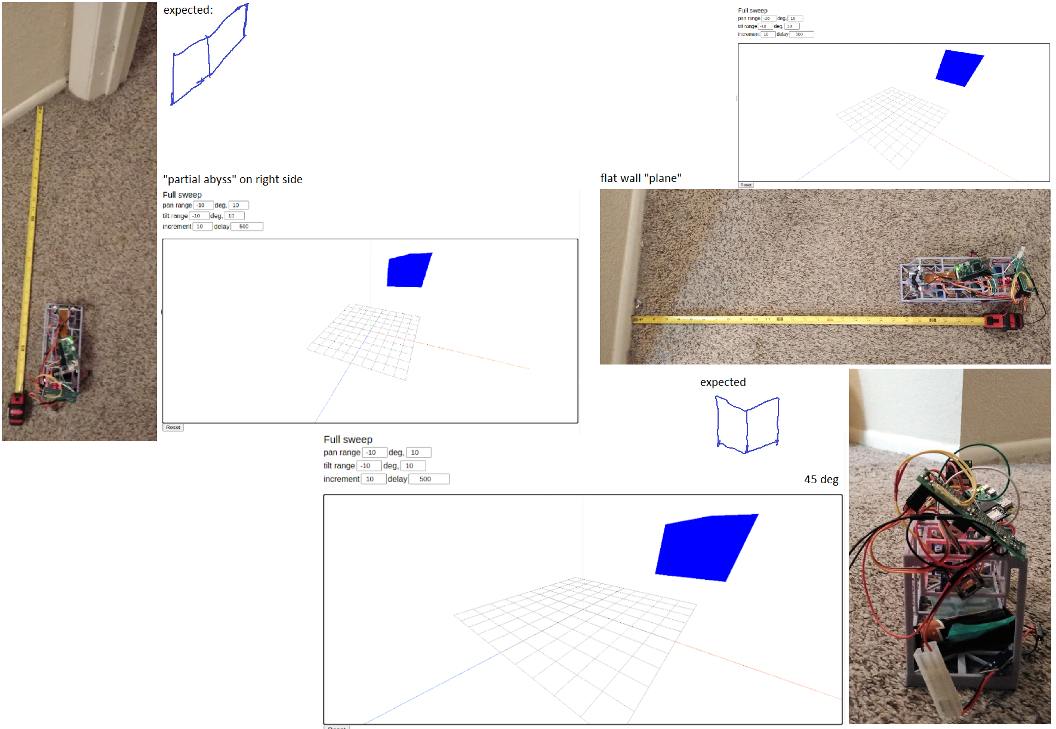
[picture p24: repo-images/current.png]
you are failing doctor


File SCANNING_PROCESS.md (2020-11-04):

### Here is an example scanning workflow

#### Sweep only, no OpenCV
#### Example scene
This is a dark box with two angles, very simple shape.

example object in frame

This box is a foot away, I don't know the angles. It does not have to be exact down to half an angle or something, point is to at least be able to see this thing with two faces that vary in angle.

I did notice when taking a photo, the box looked closer.

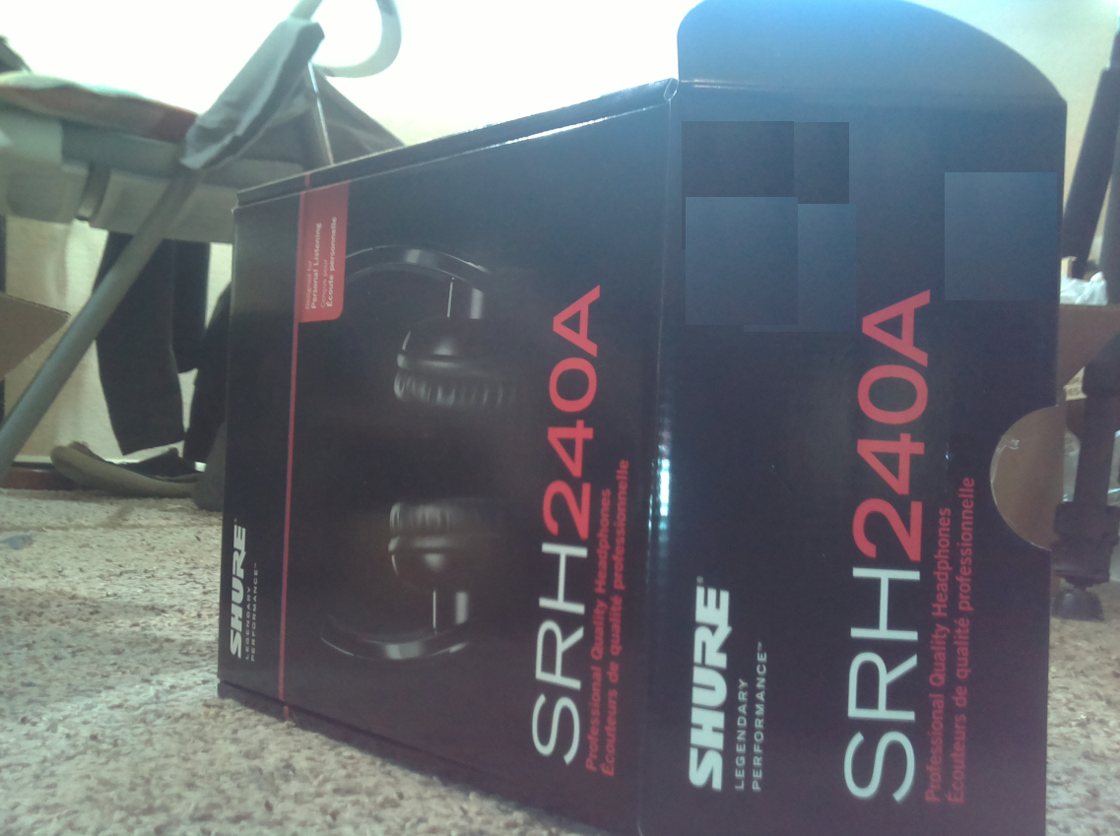
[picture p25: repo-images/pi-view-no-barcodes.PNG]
that fov


The intent is to be able to generate faces like this(for visual and for collision math)

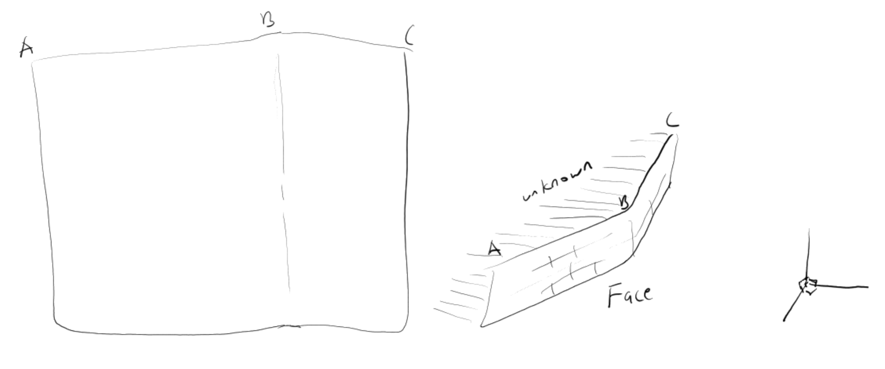
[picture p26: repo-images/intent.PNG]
intent


#### Actual code workflow
##### Web interface
- match sweep time
  - simple test, run a sweep command slow speed, manually run sensor measurements
    can use ultrasonic sensor high sweep speed sampling for nearby profiling
  - so... that's kind of disappointing, the "lidar" seems to work best if it's around or at least 2ft away
  - the ultrasonic sensor on the other hand seems pretty accurate... so maybe I can do "long range" scanning with the "lidar" and do some close profile sampling with the ultrasonic sensor, trying 1.5" as the range
  - for the "lidar" there is a 2-3cm accuracy people pointed out... so I positioned it 18" or 1.5ft away in cm that should be 45.72 but I get 51 which is just under 20"
  - ultrasonic sensor on the other hand is bang on at 18.27 in
##### Pi
##### Arduinorepo-images/intent.PNG

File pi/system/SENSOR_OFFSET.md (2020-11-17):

In the grand scheme none of this really matters due to the awful tolerances both in terms of mechanical design and sensor reliability.
You can see below the issue. I believe when I designed this "sensor assembly" months ago I only centered the sensors vertically.
I did not consider the front/back(z-axis) centering. I also was not entirely sure where the waves technically started/propogated from.
I guess it's at the face of the sensor cylinders but maybe it's at the board level.

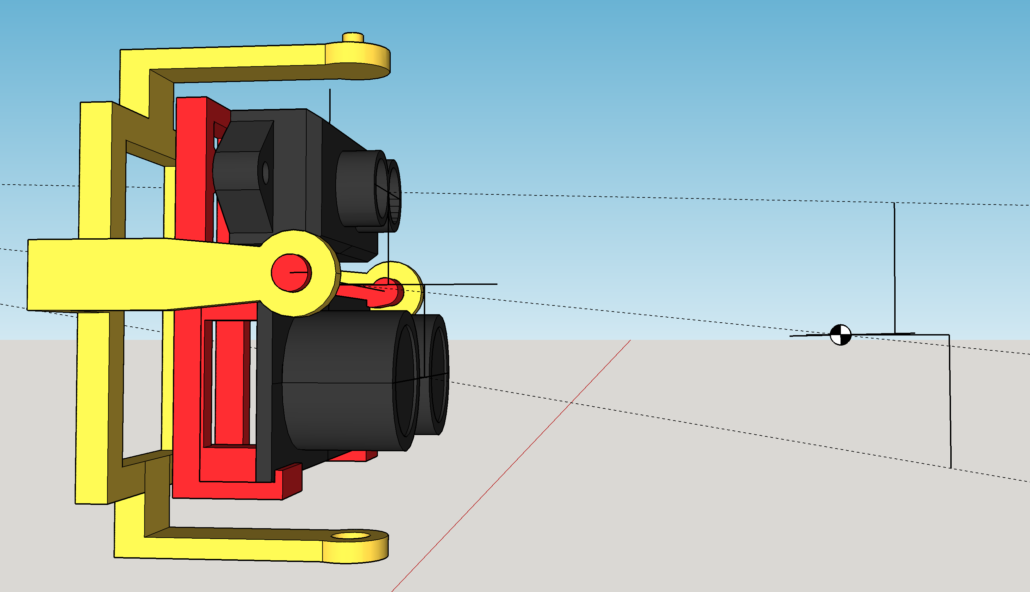
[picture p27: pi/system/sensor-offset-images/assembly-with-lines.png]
mechanical design iso view


So what I need to do is create a function where you feed in the sensor/angle and get the offset(whether it's add or subtract)
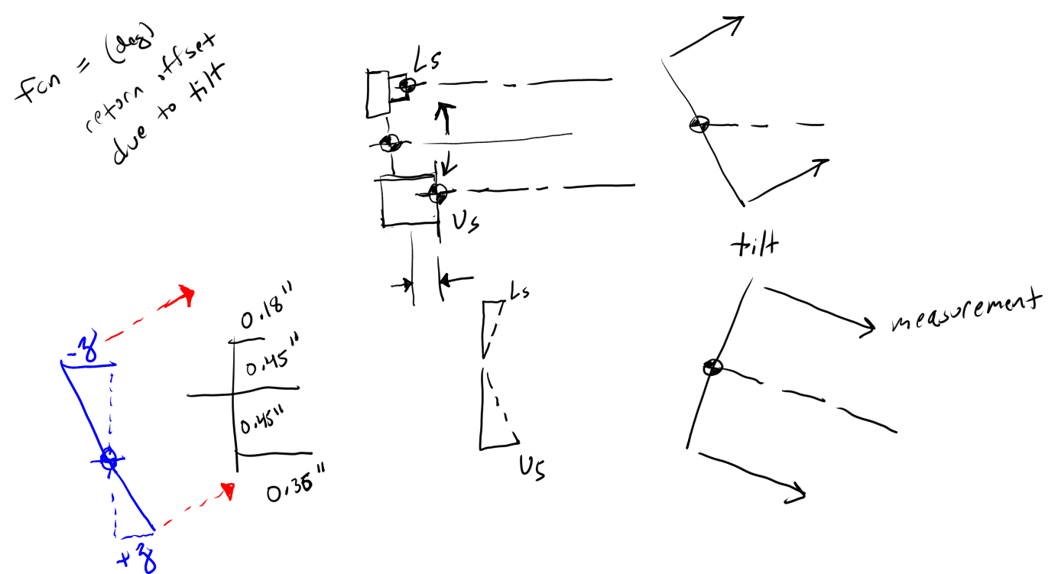
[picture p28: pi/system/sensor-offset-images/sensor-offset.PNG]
function considerations


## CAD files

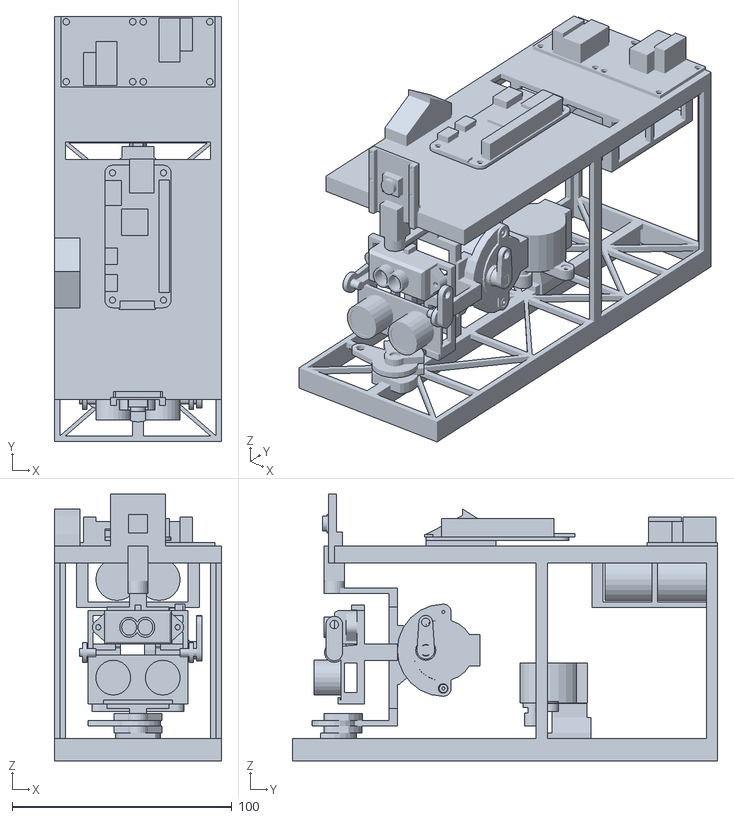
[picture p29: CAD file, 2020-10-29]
3dfiles/full-body-stepper-version.stl
76.2 x 193.5 x 121.5

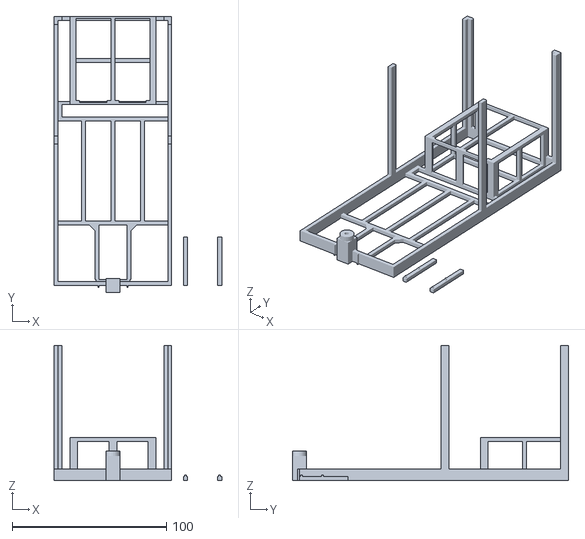
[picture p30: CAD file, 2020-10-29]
3dfiles/stl/overhead-camera-mount-sensor-assembly.stl
108.7 x 179.0 x 87.6

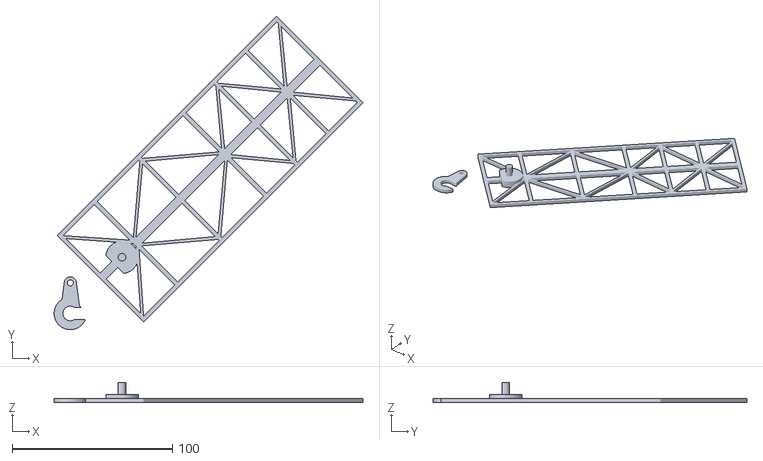
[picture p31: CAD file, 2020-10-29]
3dfiles/stl/base-swivel.stl
192.7 x 195.5 x 12.7

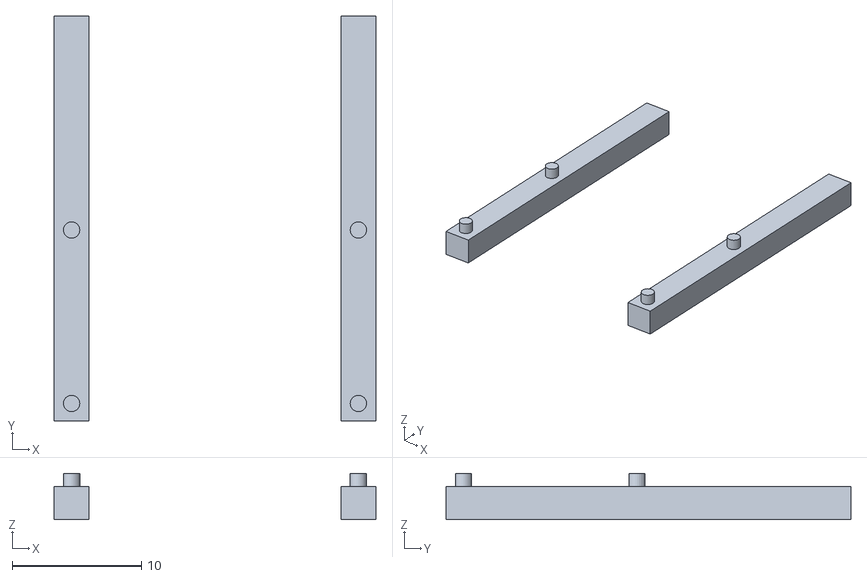
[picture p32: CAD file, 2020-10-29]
3dfiles/stl/Untitled-5f825a7e.stl
24.9 x 31.4 x 3.57

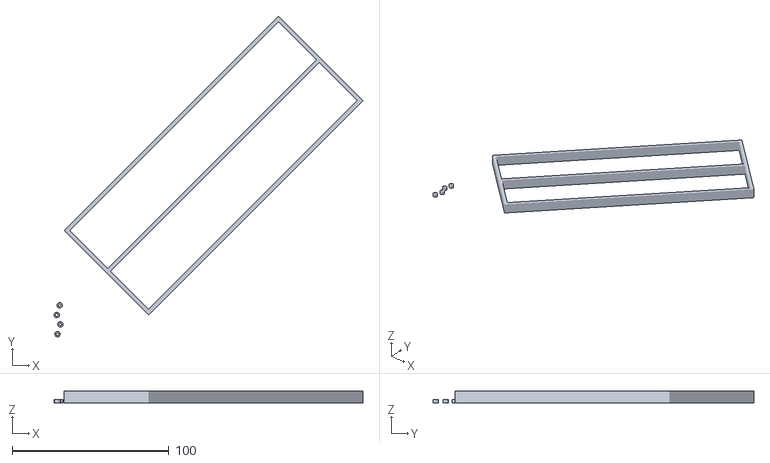
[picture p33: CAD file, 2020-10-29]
3dfiles/stl/stabilizer-for-base.stl
197.1 x 204.7 x 7.62

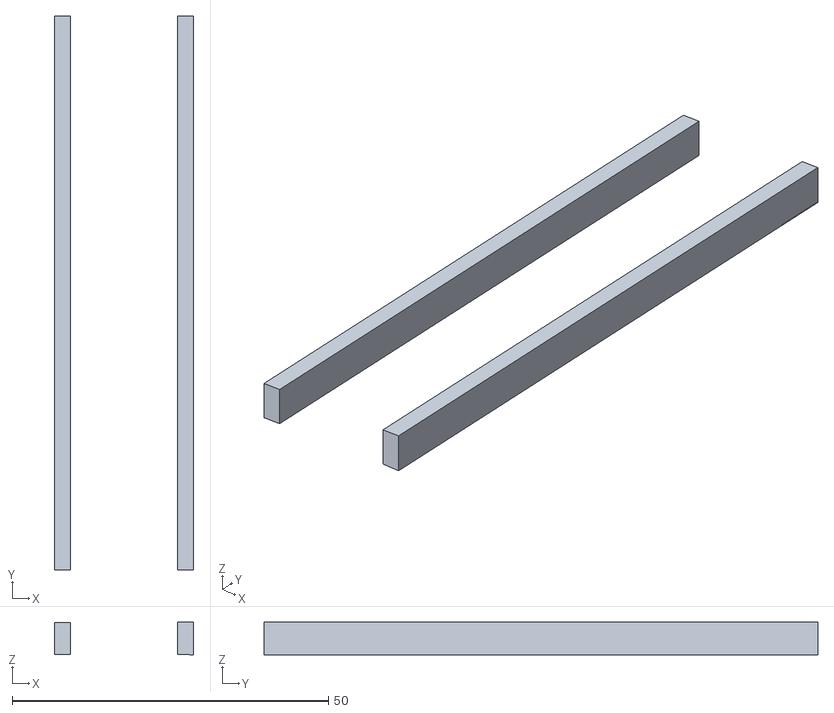
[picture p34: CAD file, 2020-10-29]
3dfiles/stl/forward-vertical-supports.stl
22.0 x 87.6 x 5.19

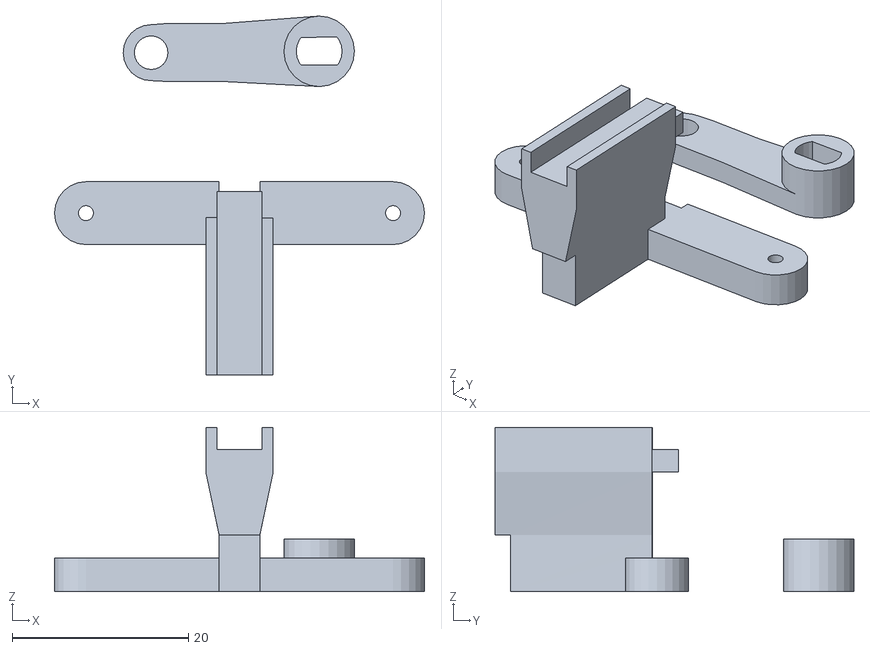
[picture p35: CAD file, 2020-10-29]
3dfiles/stl/pan-stepper-base-mount.stl
42.0 x 40.7 x 18.7

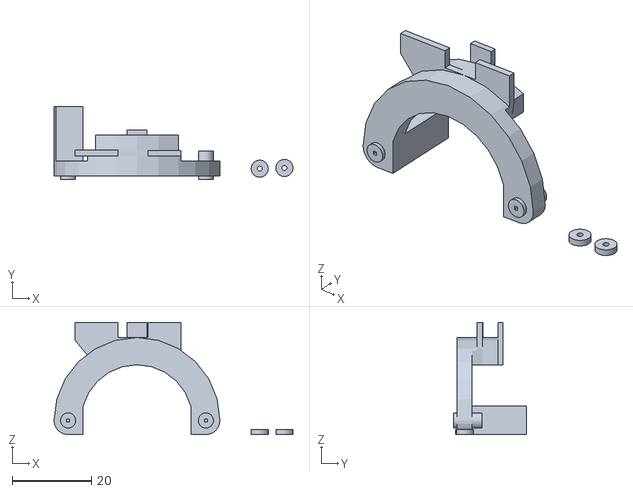
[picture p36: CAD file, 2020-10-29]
3dfiles/stl/stepper-pitch-mount.stl
60.4 x 18.4 x 28.4

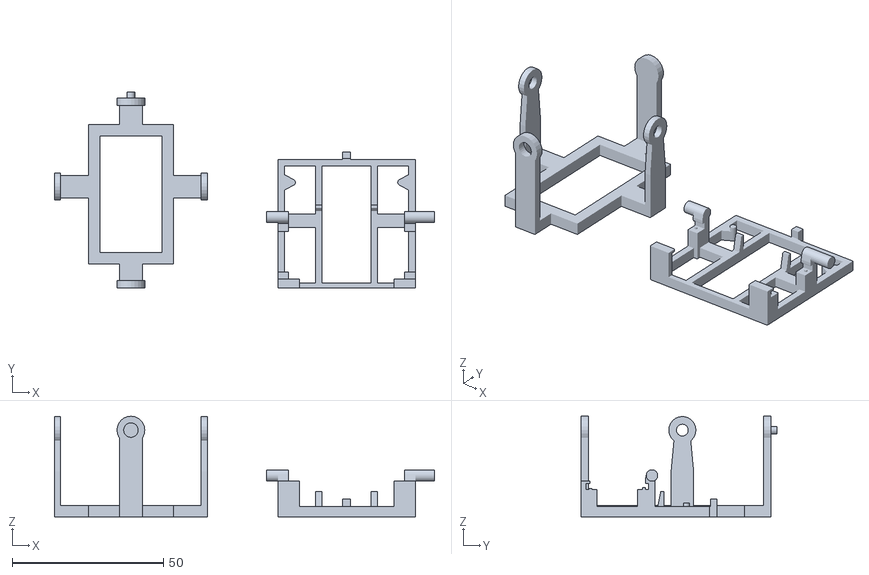
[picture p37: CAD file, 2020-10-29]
3dfiles/stl/pan-tilt-parts.stl
125.6 x 64.9 x 33.3

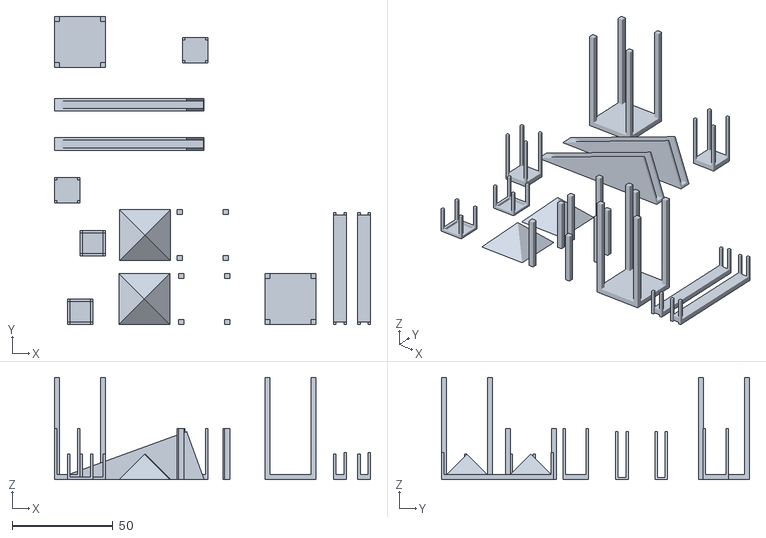
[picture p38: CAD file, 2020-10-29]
3dfiles/stl/raised-figures.stl
156.9 x 153.0 x 50.8

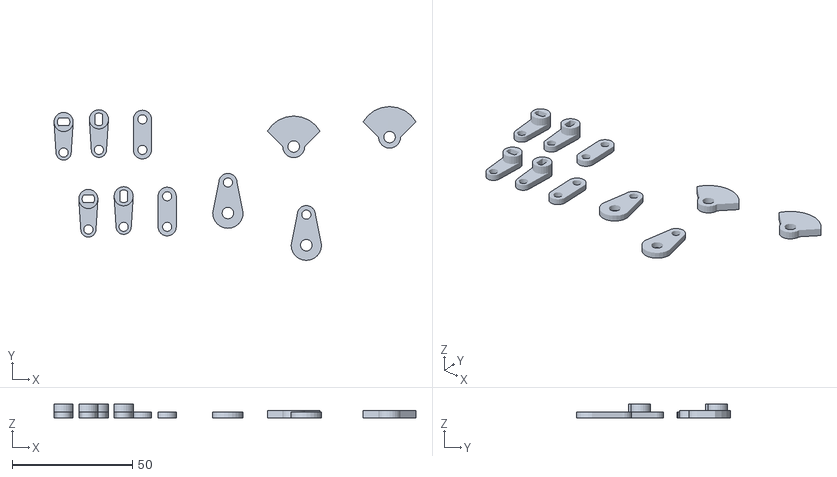
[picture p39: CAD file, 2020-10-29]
3dfiles/stl/stepper-horns-parts.stl
150.7 x 64.0 x 6.00

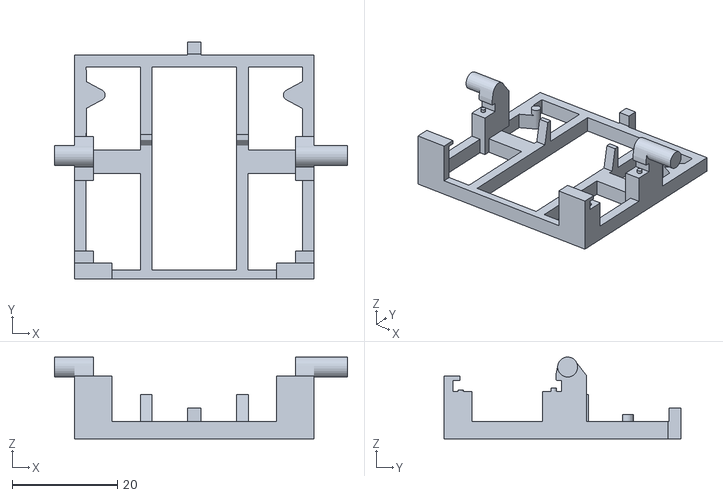
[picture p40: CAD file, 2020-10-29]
3dfiles/stl/pan-base.stl
55.6 x 45.0 x 15.5

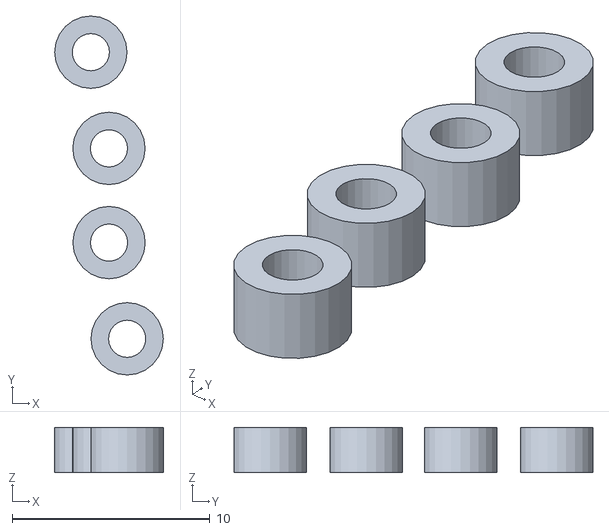
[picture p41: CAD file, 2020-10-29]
3dfiles/stl/pushrod-filler-bushings.stl
5.49 x 18.1 x 2.29

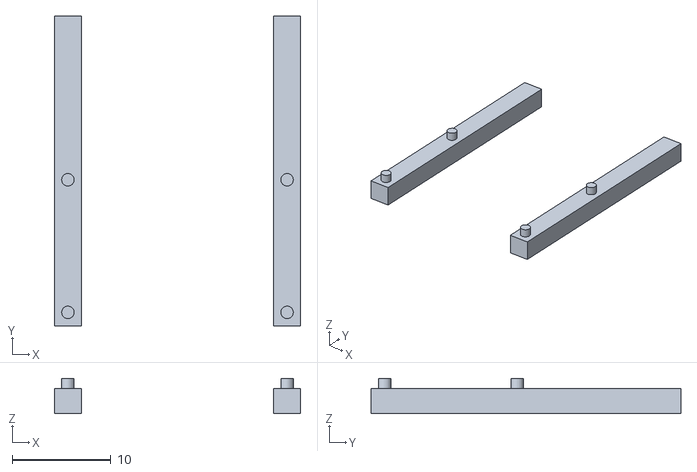
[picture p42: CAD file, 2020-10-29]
3dfiles/stl/vertical-camera-supports.stl
24.9 x 31.4 x 3.57

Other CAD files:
3dfiles/stl/tilt-base.stl
3dfiles/stl/stepper-pan-tilt.stl
3dfiles/stl/pan-tilt-axes.stl
3dfiles/full-body-stepper-version.skp
3dfiles/skp/2-cell-li-ion.skp
3dfiles/skp/5mp-camera.skp
3dfiles/skp/5v-ubec.skp
3dfiles/skp/Lidar.skp
3dfiles/skp/Stepper.skp
3dfiles/skp/UltrasonicSensor.skp
3dfiles/skp/base-swivel.skp
3dfiles/skp/overhead-camera-and-electronics-mount.skp
3dfiles/skp/overhead-camera-mount-sensor-assembly.skp
3dfiles/skp/pan-stepper-base-mount.skp
3dfiles/skp/pan-tilt-axes.skp
3dfiles/skp/pan-tilt-base.skp
3dfiles/skp/pi-zero.skp
3dfiles/skp/raised-figures.skp
3dfiles/skp/single-cam-stepper-reference.skp
3dfiles/skp/single-cam.skp
3dfiles/skp/stabilizer-for-base.skp
3dfiles/skp/stepper-horn.skp
3dfiles/skp/stepper-horns-parts.skp
3dfiles/skp/stepper-pan-tilt.skp
3dfiles/skp/stepper-pitch-mount.skp

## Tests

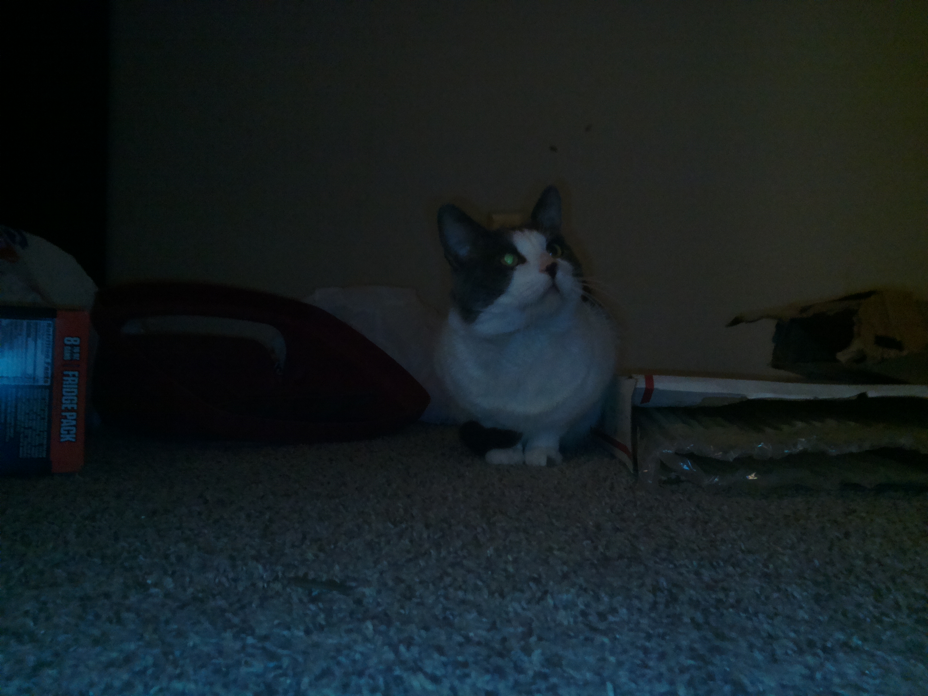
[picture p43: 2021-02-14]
vision/testing/sample-images/low_light_trash_cat.jpg

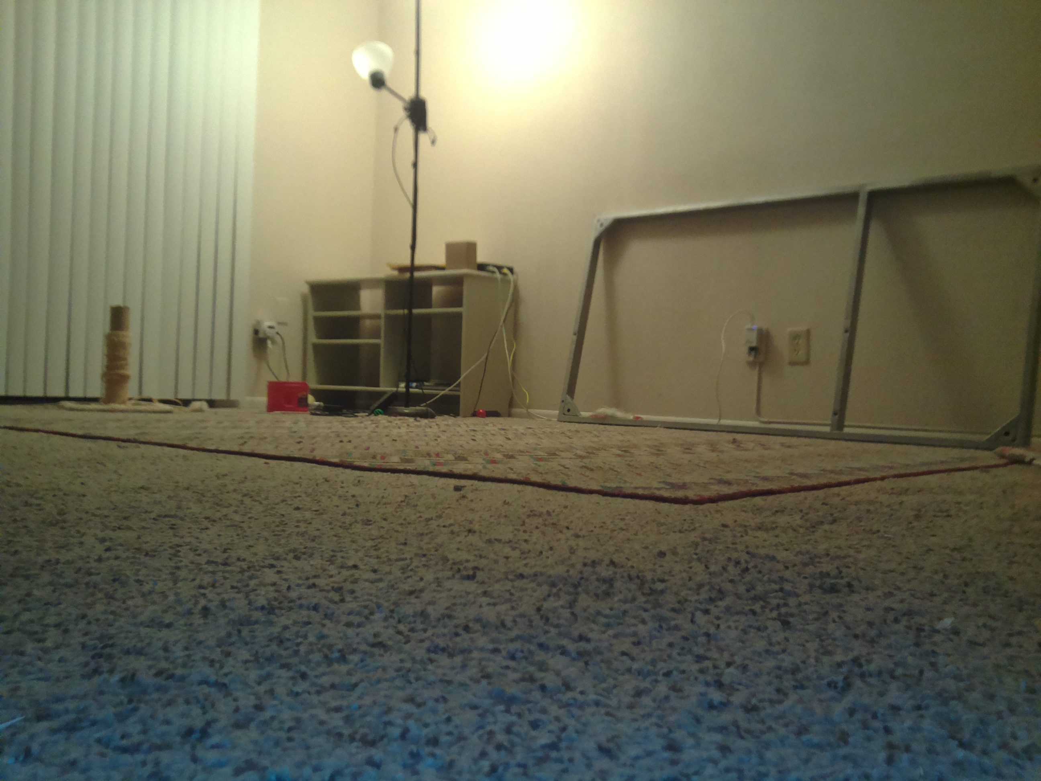
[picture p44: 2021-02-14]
vision/testing/sample-images/wide_open.jpg

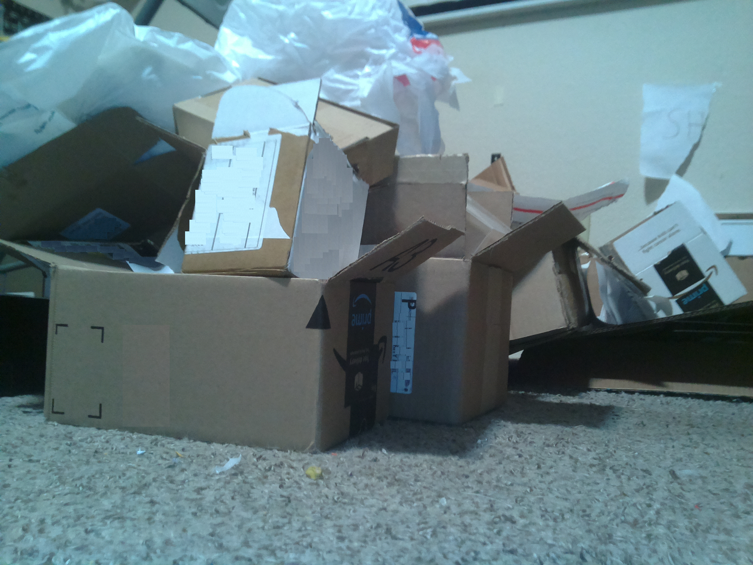
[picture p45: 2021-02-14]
vision/testing/sample-images/room_boxes.jpg

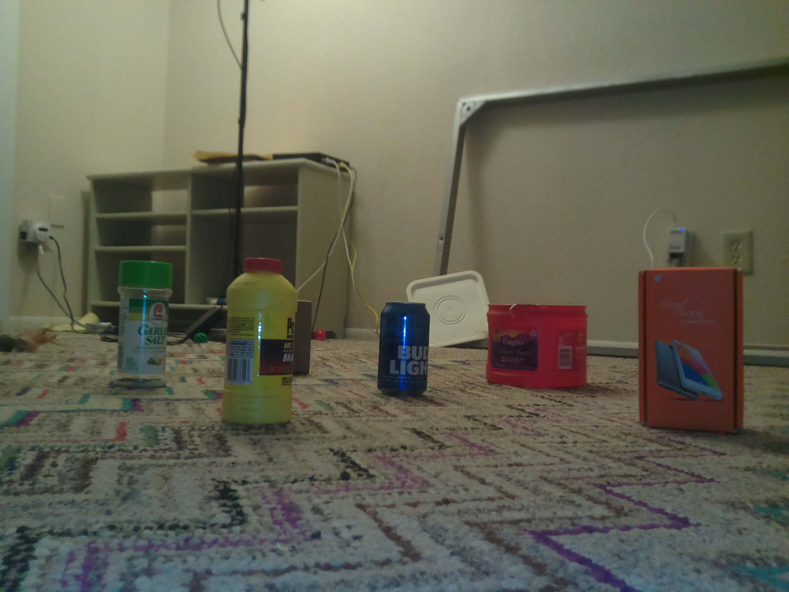
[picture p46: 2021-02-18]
vision/testing/sample-images/assorted_color_items.jpg

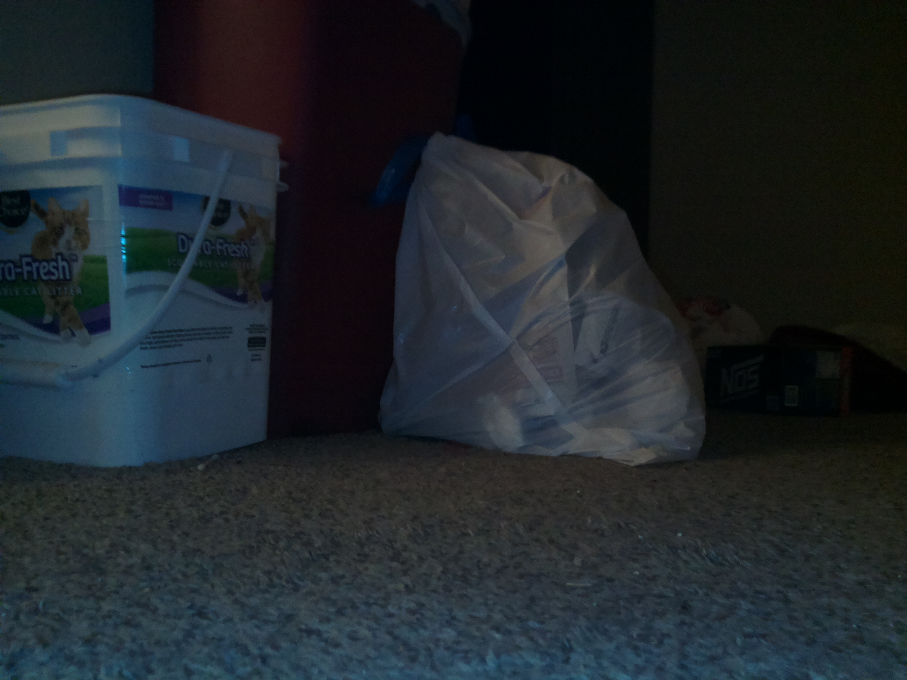
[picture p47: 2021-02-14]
vision/testing/sample-images/dark_hallway.jpg

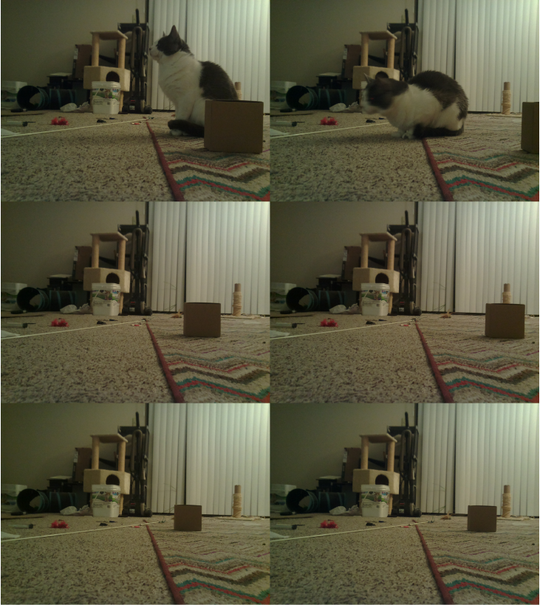
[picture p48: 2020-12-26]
vision/testing/distance-sampling/sample-images.PNG

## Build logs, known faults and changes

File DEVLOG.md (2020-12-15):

- ### updates
  - [ ] dpad
    - [ ] add bars/slider
    - [ ] add quick center
    - [x] add setup of major/minor ticks eg. increment by 1 vs. 5
      - only one input but variable
  - [ ] move servo code
    - [ ] add callback when seharvo is done moving, or add matching delay before buttons enabled/able to move again
      - callback from Arduino i2c probably better in case comm delay

- ### reminders
  - socket service user specified is pi to have access to smbus2

- ### "Geometric error"
This is due to the sensors rotating about an offset shared central axis particularly for pitch
Pan has its own problems(since the sensor emit/return are not on the same point/axis)

### Extra
- should be able to add something new/last minute say while robot is moving
  - can somehow pick it up... not sure how, maybe frame by frame diffing idk

### Next
- [ ] add background task to Arduino code to unblock itself
- [ ] add reset btn on ui/feed to Arduino
  - happens when some process in Arduino doesn't finish and global variable "something in process"
    left to true
- [x] fix issue with rerender on input after threejs has rendered once
- [x] fix math and update plotting for threejs/add toggles
- [ ] add led lidar
  - test it
  - add as secondary check to confirm measurements
    usensor bad on corners facing away from sensor
- [ ] add method to plot robot as rectangular box in center of ThreeJS plot
  - make sure it's vertically simulated correctly based on camera and possibly if mounted on wheels

### Get camera samples
Need to take sample photos at known distances from camera in Z direction. The item does not move in x-direction.
Known size of object shows it sliding left/right and how much so can estimate angle to point sensor assembly.
Will take initial straight on measumrent if nothing's in the way
### 12/11/2020 later

I'm going to try and come up with the offset function for the sensor aiming from camera.
I'm using SketchUp/3D program to work it out.

5.4 deg right, start pos 94
7.1 deg down, start pos 89

245cm -> 96.5in straight forward measurement
first angle attempt 5 right, 7 deg down
123 -> 48in

I just realized the web interface doesn't have a granularity that far eg. 0.1
Also currently don't have web triggered/response measurements, I'll have to try these manually.
This is actually pretty hard.
Initially I had plans to use a laser pointer, that would have been a good idea to have but hard to mount to sensor, adds more offset.

Ugh... these sensors man it's 2" off the "lidar"

38.25 to 38.5" away

Ehh... I don't even know if this is the right way to think about it. It's interesting if you point your arm/hand at something and then close either eye/see if it lines up with the target, it probably doesn't. It does relative to your eye/dominant but moving your head you can see your arm pointing somewhere else. That offset is what my dumb brain is trying to figure out what the formula is.

This is a simplified drawing over an image but it's a shot in my room/office/workshop. Everywhere else it's about 8feet deep but the box is the 38.25" away mentioned above.

I think this is correct, the box is the photo and I actually brought it in/scaled it down and it matches. The big box is 37" across and whatever value vertically to match AR and it's 36" away. The angle is a "3D angle" I think, so I'm trying to add planes in to extract the up/down and left/right angles.

I'm pretty mentally spent today so not sure if I'll really be productive.

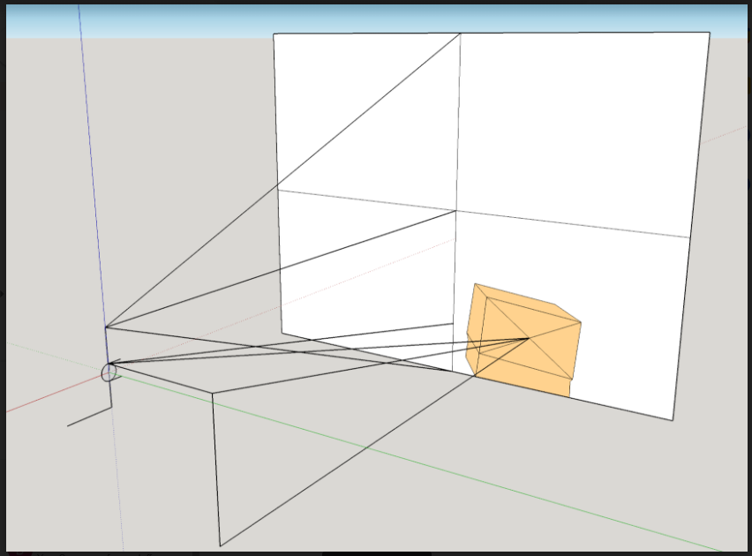
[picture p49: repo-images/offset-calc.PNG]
calculate offset


### 12/11/2020
Alright, brief break, fresh brain kind of... will see how this goes. I want to update the README as the main image is a bit misleading. That was my plan till I later realized how grossly inaccurate my setup/sensors are.

external view

Here is an example of an easy layout/obstacle. This is arguable you can just do it with an ultrasonic sensor but the robot still is "dumb". This image is also concerning regarding that metal frame in the back, I imagine I could pick it out with OpenCV but then it's a non-simple, non-solid-block shape.

This is the simple workflow so far:
- Camera
  - OpenCV
    - histogram for masking HSV ranges, masking, contour bounding, get bound center coordinates
- Ultrasonic/"lidar" sensor
  - get distances
- Python/ThreeJS
  - gather and store points
- IMU
  - update stored points based on accelration/velocity/estimated position
    - want to have "not having" as well in case it's trying to move but something is blocking it
- Plotting/world view
  - show where Robot is roughly and tracked objects in 3D

This will be interesting because I was never really a math guy, I got that brick brain.

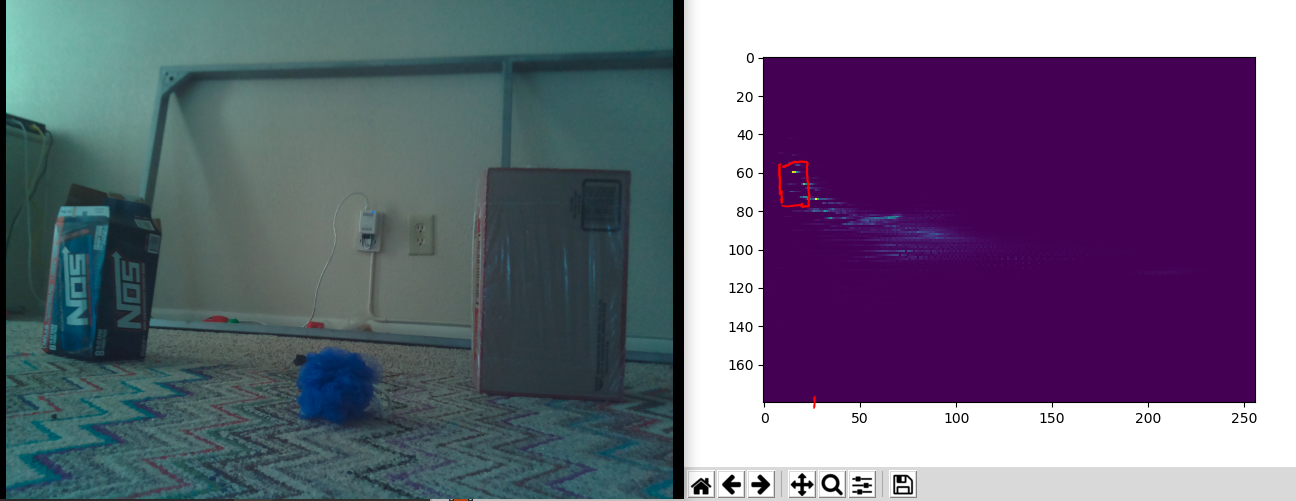
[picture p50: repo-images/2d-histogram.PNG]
open cv example histogram


So... this is not good, the histogram ranges are too close together so I'm thinking that means it will not be easy to isolate things.

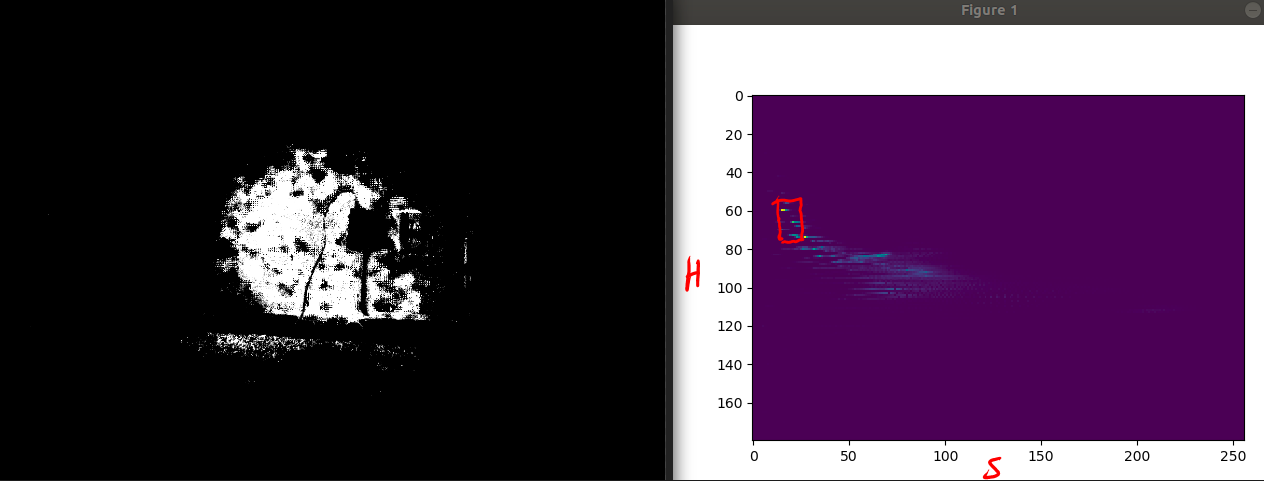
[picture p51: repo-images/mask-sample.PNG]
example mask


Yeah this is interesting, probably one of those averaging-sample thing(see squares on histogram)... yeah maybe this is a complete failure idk.

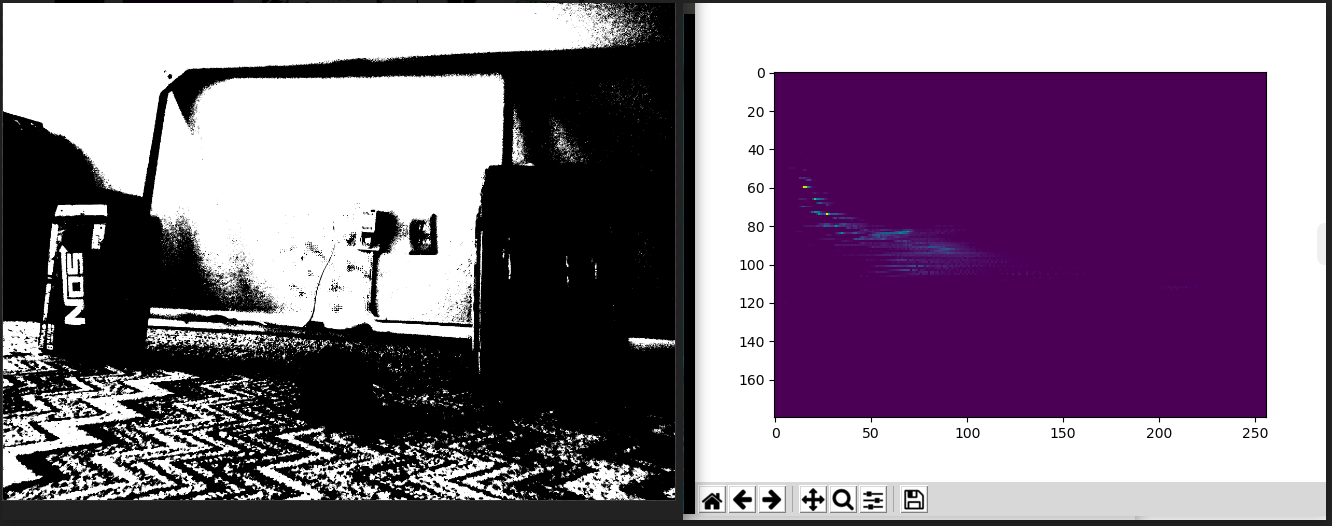
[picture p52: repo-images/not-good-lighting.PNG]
not good lighting


If I do a full bound I get to see the entire picture. Modifying the "lighting" part eg. V will probably make things more/less obvious.

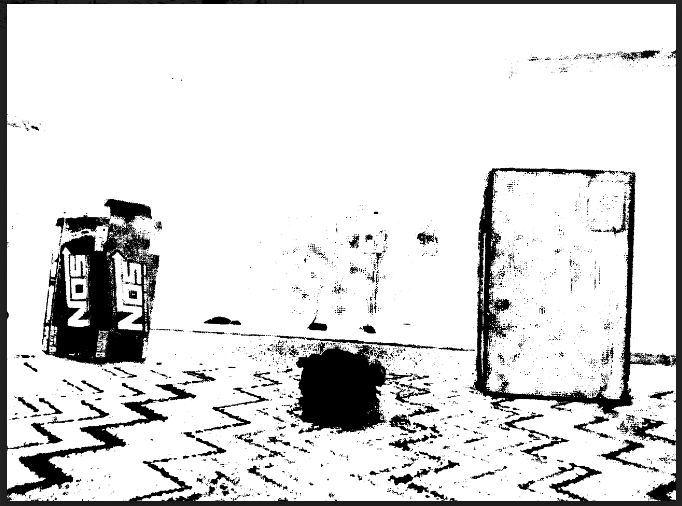
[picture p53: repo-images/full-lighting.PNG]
full v lighting


Oh wow `0-255` V value is more obvious regarding finding the big stuff. I can do a bounding sample on this. Haha... drew contour around entire thing. One of the things I have to add is an array of the areas and then I can "descendingly" check them out against some threshold like "only care about # square pixels"

Hmm... kind of ran into a small wall here, while I was able to sort the contour areas in descending order, they don't seem to behave as I would expect when plotting them... if I plot areas that have near 0 area the biggest squares appear...

Nope I made a mistake, I was using the loop counter as an index against the saved contours but it should have been the index saved with the area. I'm developing on two different computers so I don't have code to accompany these words until I put it all together.

found boxes

The square in square is interesting, I suppose that is possible like a small box in front of a bigger box.

What is also concerning is the lines on the floor... it is possible those are not on the same plane/actually vertical. You'd need something to figure that out based on the direction of the dots/contours to figure out it's a plane/ground.

So yeah... I think from this I can tell depending on circumstances (same average light distribution/clustered 2d histogram) that I will need to use full lighting/maybe do a wide physical sensor sample to confirm.

The floor/horizon detection is interesting too.

#### sensor targetting from camera

I'm going to try and reason out the camera aiming now (excuse to charge Ubuntu laptop where I do OpenCV).

Once I have a full workflow setup, will be nice to just run a command and it will do the photo/outline stuff/send it to the webserver and then I can see if it's performing the right "algorithm" for cleaning up/sampling an image to find objects.

### 12/10/2020
Putting a little bit of time in. My brain is not phenomenal I still feel ike a monkey when I can't immediately get some spatial thing. Anyway I took this picture as a reference, shows what the camera can see full resolution. Man idk why this camera sucks but it also wasn't expensive. It's good enough for blob detection.

Also interesting how much of "below the horizon" it sees at the height relative to the floor as a reference

still don't know

Still don't know yet how to point the sensors at something in picture.
Ugh... my brain sucks. Going to cheat with Sketchup/Cad

For example at 3" the bottom sensor(ultrasonic) has to angle itself 4.5 degrees up to point at the center of the camera frame.

I think aside from general "inference"? Interpretation... idk... I could at the very least do a center sensor sample to get an immediate depth... may suck if something is in front of the object but you could assuming having easy contours use that object as an estimation for everything else based on its bounding box contour size...

There's a relationship though, at least it's a simple right-angle triangle. Half of 36" away it's 9 deg angle up.
The Lidar is a little different, 3.1 deg for 36" and 6.2deg for 18"

Image AR is 1.33 (4/3) or 0.75 (3/4)

Well not scientific at all but can see the camera view angle vs. the sensor angles to point at the same thing due to offset

sketchup madness

### 12/09/2020
Camera targetting and offset
- [ ] be able to take a picture and based on bounding box/centroid from OpenCV aim lidar/ultrasonic sensor assembly to get distance 
  - example is 4ft foreground(target), everything else is about 7ft away
    - target is 72 square inches

I'm super burnt today, working on this EOD... but today was productive though, a little bit of breathing room.
One of the things I don't understand at the moment is the focal thing of the lens... so if I see something that's 9" across and it is whatever inches on the screen at some pixel... can I roughly know how far awy it is based on that FoV value or whatever.

For now will just work on the basic workflow that will determine the quadrant/point/angles to apply and then use the lidar for the distance ping... if it's closer than the threshold eg. 2' will use ultrasonic for more accurate measurement.

I'm using Gimp to figure out some... well actually paint is fine too. Just need to split the image up into quadarants.

One of the problems is the offset of the camera center with regard to the center of the pan/tilt 

This is the mechanical offset situation... yeah I'm really burnt... can't think anymore. But this is my top priority now personally I want to do a nice writeup/video on this once I have a system that can run on its own.

need to update with math

### 12/08/2020
I did put some time into the panel-splitter-plotter thing(ha). It works now and I added random color to the tiles but the values from the sensor are awful. In particular say facing a corner(with middle closest to cam). It's like measuring infinity or something with the ultrasonic sensor/possibly mismatch of sensor still moving while trying to measure(no feedback).

tears

I did make great progress on the OpenCV part. Some heavy StackOverflowing for that. It's still not written where "it just works" but I have the process down. See this example here where I was able to dynamically figure out the right HSV masks to put bounds around objects in a random picture.

in rain

This project is now top of my list of things to complete though outside of work so I'm hoping to get a write up completed maybe by end of this month December 2020.

I think for the "full workflow prototype" I will just use single-point sampling and treat everything as a box with generous margins of error. Maybe try averaging the "lidar" and ultrasonic sensor measurements.

The IMU aspect is still a big unknown for me at this time.

### 11/26/2020
Well... been busy lately, now have some free time, fresh brain. I had lost interest somewhat, there is still a bit of work to do.

- [x] sweep command stopped working(no change but updated Python cmd string send to Arduino)
  - weird, logged the command ex. `s_p-010,010_t-010,010_i010_500` seems the delay is ignored, sweep sample still works
    not sure if problem is on command part or on Arduino side, no sweep sample is also broken/ignoring the delays
    I will see if reflashing the Arduino code will help(why)
    Oohh look at him, hackerman
    hackerman;
    I do love this giant monitor though, look at me ma! I can SSH
    Anyway I'm adding logging back into the Arduino code to see if it's parsing all the command string characters
    Well it's working again... not sure if the serial print had anything to do with it but the sweep sample while it works has undefined at the end of it... probably a CLI args read issue, but it doesn't seem to affect it so... ugh... I'll fix it. I have to modify either the nodejs code or python code and then reload the systemd service on the Pi.
    Sidenote the Surfacebook is a cumbersome device due to it being top-heavy(tablet is heavier than keyboard). I also have this anxiety about both batteries matching percentages. Still I remember holding one of the first Surface tablets in my hand like 10 years ago... way out of my budget, got this one used. It's cool but I have not really used it yet regarding the tablet aspect.
    so it was literally sending the string "undefined" from node to Arduino... I acknowledge this code is trash
    Anyway I'll remove the serial monitor logs and see if the sweep stuff still works
    One thing I have to do is estimate current consumption, just doing a "started at this voltage, ended with this after x hours", not really sure if that's considered current consumption but I can at least gauge approximate lifespan from 1, 18650 3.4Ah cells.
    madness
    sitting "idle"
    3.641V at 11:36 AM
    3.522V at 12:49 PM
    3.301V at 2:13 PM
- [ ] finish function that takes in parameters `(distance, sweep, tilt, increment)` and returns the coordinate pairs for the vertices to make the "plane" or polygon
  - pan pattern starts top left then goes to top-right
  - [when your meager brain cells collect into a pool and somehow establish thought](https://www.youtube.com/watch?v=ZeFonavUHTg)
  basic trig
  I prototyped out the code to generate the points but  I'm still missing the groupings to generate the mesh/planes
  proto-scopo
  seems I have to reset the Arduino if the delays are ignored...
- [ ] start on OpenCV side that scans an image for color groups and then aims the sensor in those directions to get a sample... perhaps can find the corners in a simple case and create approximations(planes) at the appropriate distances
  - so many of the OpenCV tutorials online literally just code out what are in the docs... it's like "we're going to find the red cup" wow! Amazing... every freaking video man.
    it's like, no, I need to be able to find a dynamic range of unknown colors, how do I do that?
    It will be cool when I reach my goal about the "real time running world coordinate system" (bs) regarding the known world position of the robot based on IMU values, stored 3d point objects not only for ThreeJS visual but the mirror that's running in Python for the robot's navigation, ThreeJS is just a human visualization thing.
    I've never built something like this before so it's cool if I get something that remotely works, I realize it's trash and not real time like waving around an iPad in a room to generate a 3D mesh/point cloud collection but still... if it can navigate a robot that's the main goal
- [ ] add "connecting..." ajax spinner to status indicators
- [ ] fix the reset/remove ThreeJS canvas issue

### 11/10/2020 (later)
- [ ] make first demonstratable single-button click that results in rendered mesh on web ui
  - [ ] web ui
    - [x] add basic input for pan/tilt/step ranges
    - [x] add the render area where threejs mesh will show
    - [x] update websocket code that communicates down to pass the new command string
  - [ ] threejs
    - [ ] clean up starter threejs code so can add more to it
    - [ ] add planned body of 2-wheeled robot with big sensor box
  - [ ] pi side
    - [x] parse and send command to Arduino(maybe no change needed with current bad implementation)
  - [ ] arduino
    - [x] update command parser so it can receive more data
    - [x] add the nested loop to do the multi-axis/range sweep

### 11/10/2020
This todo list has become more of an insanity log. An update from before, I initially was trying to learn WebGL but thankfully I found the path of Threejs.
After doing the panic Google session and countless threejs examples/stackoverflow questions I have formulated the basis for the visual rendering.
Earlier(few days back) I wrote the basic math functions to take the measurements coupled with the pan/tilt angles to generate the 3d coordinates... which also need to get cleaned up still.
Anyway I am at the point now where I can make a visual representation of it in 3D to be displayed on the web.
It's not part of the navigational system that will be all in memory but it is a nice-to-have thing. To map the world/gather data and update it based on kinematics(onboard imu).
Mostly I needed a quick burst of "I'm not a failure" even if it's a fantasy/joke what I'm working on.

I'm working with the sample coordinates mentioned below. I still have to investigate why 20+ deg tilt is ignored/cancelled... probably some dumb code in Arduino that I wrote.

I can't spend too much time just wanted to visually display the points below in 3D space using Threejs.

Well... this is not correct at all since I had to throw away a lot of the values and I think the mesh drawer that makes this 3d shape just joins stuff.
If you're looking at this it's not even correct, the point(corner of wall) should face the camera.

something

Anyway it's a a start(ain't much meme)

### 11/05/2020
- [x] look into why the angles don't match
  - due to mismatch horn lengths and the horns weren't parallel to each other from the start, only affected pan 
  - updated horn(extended) and updated center points
- [ ] try simpler set of points, see if can plot a plane
- [ ] read through webgl example code
- [ ] full functionality eg. from web command to scan/display webgl "meshes"
  - determine the string command for box scanning
  - do full math
  - add other "callback" part on front end that runs after certain time has passed(dumb) depends on number of points
  - pull the values hosted by pi server
  - plot in webgl
  - then start doing the world mapping
  - add imu
  - add tracking
  - add collision detection
  - add OpenCV blob finding and combine that with above for determining what to scan and plot in world
  - add coordinate find from image and factor in offset based on camera overhead position and pivot point of sensors, general accuracy errors
  - collect data
    - corner wall at 45 degrees, 2ft away
    - us
      - 20 - won't sweep
      - 15 - won't sweep... will have to investigate Arduino code, watch serial
      - 10 - [39.86, 33.91, 34.12, 33.91, 33.87, 34.11, 34.25, 34.59, 34.47, 35.24, 35.68, 39.99, 41.19]
      - 0 - [24.38, 34.18, 33.98, 34.19, 33.99, 34.29, 34.15, 34.35, 34.66, 34.89, 39.42, 39.49, 39.63]
      - 10 - [35.44, 34.29, 34.07, 34.45, 34.08, 34.25, 34.25, 34.35, 34.81, 35.79, 39.71, 40.01, 39.86]
      - 20 - [40.24, 34.72, 34.97, 34.5, 34.84, 34.99, 34.71, 34.82, 35.44, 39.61, 40.73, 40.45, 41.13]
    - lidar - measurement stuck at 65533, not sure if broken or battery
      - it was the battery, after putting in a fresh cell at 4V, was working again, it's bad as I mentioned around 2ft but I measured 38" and it was off by about 0.5"
        vs. 2.5" or so when measuring 18" but received 20.5" as a measurement
      - 20
      - 10
      - 0
      - 10
      - 20

### 11/04/2020
- trying to actually get something done today
- [x] test angles see accuracy and if measurements still work
  - [x] verify angles visually
      - this is not very accurate at all, the accuracy magnitude I had planned initially is way off at least for the "lidar"
  - [x] check measurements from ultrasonic sensor
    - usensor face is 0.5" off (less) from pan/tilt axes, also seems like camera face is 3/8" back from us sensor face
    - yeah this thing is unfortunately f'd since the part where the beam/wave leaves the sensors are not directly in line, there are offsets
      especially when it rotates about the wrong axis
    - rotate 10 deg right, measured 17.73" + 0.5" => 18.51" compared to expected trig value: 18.28" -> 0.23" margin of error
      try again
      10deg -> 18.23" expected, actual is 17.51" + 0.5" -> 18.01" -> 0.22" error
      20deg -> 19.16" expected, actual is 17.72" + 0.5" -> 18.22" -> 1.44" error oof
      30deg -> 20.79" expected, actual is 18.1" + 0.5" -> 18.6" -> 2.19" error ahhh
    - try lidar at 2' -> measures 26.38" -> now bang on at 61cm or 24.02"
      10 deg -> 65.5 cm (avg) -> 66cm
      20 deg -> 66 cm -> 97cm on second measure going backwards
      30 deg -> 78 cm -> 
      ehh... idk... also able to pan farther out than "limits" eg. max of 30 deg in either direction, maybe a good thing (60deg not a big fov for sensors)
    TLDR these measurements suck/not reliable, a panning/general averaging may be passable given enough large margin of errors
    Also sometimes the servos don't move... even when commands are sent, that sucks, concerning
- [x] write first sweep samples
  - ex of 5 deg incr, within 60 deg limit = 12 points -> 6 seconds duration, tested and took about 7.86 seconds to start and stop moving(recenter at end of sweep)
    - as simple baseline can sample at half the speed of delay eg. 500ms = sample every 250ms
    stuck on file writing issue
    - this is not great but I'm just creating a folder with 777 permission, inside that a file with 777 permission
      this code runs by systemd and the user is set to pi, logs confirm as pi but for some reason denied to write to file still when node calls python cli exec cmd
      setting working directory in service that runs the socket
      hmm hmm hmm... this is bad... can't get anything to write
      so... 3 hrs later and crying blood... I guess somehow the python file is cached that node calls, since I disabled the bus write line but somehow the servos
      still respond to the web ui calls
      Jesus... lmao I didn't change the new directory for this project in the socket part of nodejs so it was never calling the updated python file... ahhhhhhhhh it's fine... we all age
- [ ] come up with box-sweep string cmd
  - has to be simple defined by end limits and steps(vertical samples)
  - ex. current sweep cmd s001p500 -> sweep, 1 deg, pan, 500
  - Arduino can only understand code like above so far so python has to do the parsing/bus calls per delay
  - I think for now I will get manual coordinates then I will plot them into webgl
  - I'm doing new measurements again and it doesn't seem too bad actually the values
  - manual measurements, 7 rows (30, 20, 10, 0, -10, -20, -30)
    - what's interesting is the 0 plane referencing which sensor/around which rotation point... I tried to do that in this design but I messed it up since I didn't know where the waves propagate from
    - these values have to get cleaned up (outliers)
    [
      [17.62, 36.23, 58.89, 44.22, 59.2, 58.88, 54.89, 17.99, 18.13, 17.65, 18.2, 17.78, 18.01], // 30
      [17.5, 18.11, 17.7, 17.89, 17.52, 17.36, 17.39, 17.52, 17.58, 17.41, 17.33, 17.33, 17.55], // 20
      [17.39, 17.39, 17.57, 17.8, 17.45, 17.6, 17.2, 17.39, 17.22, 17.22, 17.05, 17.39, 17.35], // 10 deg
      [17.31, 17.67, 17.51, 17.54, 17.47, 17.38, 18.28, 17.26, 17.31, 17.33, 17.33, 17.45, 17.27], // 0 deg
      [17.46, 17.98, 17.91, 17.76, 17.6, 17.6, 17.6, 17.76, 17.62, 17.58, 17.39, 17.42, 17.63],
      [17.85, 18.06, 18.16, 18.39, 18.16, 18.0, 18.18, 18.07, 17.99, 17.87, 17.86, 17.86, 18.03],
      [19.15, 133.03, 132.53, 132.63, 132.7, 20.73, 20.06, 19.08, 19.01, 18.82, 18.75, 18.83, 18.84] // this angle too steep until mounted to frame
    ]
- [x] write trig math to get x, y, z coordinates
- [ ] maybe plot coordinates into webgl even if manually done
    - it just occurred to me that the points had to be connected to have faces... I just had dots
    so I tried a 3d scatter plot and I think my math isn't correct or how I mirrored the values isn't right.

    try plot with plotly3d js

    What I was trying to measure(the headphone box at 17.25" away from us face)
    
    top view measure

    What the camera's seeing

    camera sees

    I also realized my angles don't match eg. 3 x 10 deg increments doesn't go to 30 degrees (paper). Ooh... it's probably my servo arm length not matching the horn on the other side.

### 11/03/2020
- I think I may have a self-sustaining drive to finish this project now, where I will, "will" it into existence
  even if it's a piece of crap
- I'm thinking about how the scanner will work
  "brought to you by X1 Carbon 3rd gen" ha always wanted this laptop though I hate the left-most fn key
- scanning process, Arduino is still disconnected from Pi/Python in real time due to i2c interrupt being brief/prefer batching
  also ultimately any sort of "position/is-it-done" kind of stuff with a servo is pointless without a measurement eg. ADC on Pi side measuring spikes on servo by pot hack or something
  eg. quit using crayons and get a motor with an encoder or something
  - websocket sends command to sweep(x,y)
  - python code that talks to i2c to send simple string command sends command but also starts python sensor measurement gathering
    - all under pretense 1 second apart delays per servo motion or whatever delay sent down by websocket is honored(flaw)
  - the data is just stored, no math is performed
  - after the scan the math is performed to get the x,y,z coordinates for the 3d plotting from angle/arcs
  - these values will get read however the process is initiated from front end as part of parent event(sucks because socket is using node then talking to python)
    - some kind of bus between node/pyton I think is possible too, right now I'm using `exec` which is one directional in a full linux board at some point, the type that has mixed my use case
    - not impossible to use python socket but a PITA and having to mix python versions(also not impossible)
  - values received by webgl plotter on front end, then I can visualize it, ooh pretty the skewed piece of crap
  - next would be some world modeling/translation based on motion(IMU interface/attached to wheels)
- at some point will actually use OpenCV as the main driver
  - takes image
  - scans image for objects
  - do process above however with override to not sweep but pick specific points to probe or partially sweep
  - all based on the pan/tilt, camera fov, etc... in other words probably will suck, but once I have a full system can improve upon it
- I think I will use something like a Beaglebone in the future, try to keep the "language" a single stack, except for the web part, may go for desktop just for experience/learning
- added a `SCANNING_PROCESS.md` and `FUTURE.md`

### 11/02/2020
- crash course in lobotomy
- time to perform my magic trick of making a rock absorb blood
  - super burnt
- [x] going to try a boosted single cell battery for the first time
  - damn I soldered first one backwards in polarity, magic smoke... glad I have several
  - working now pretty cool first 18650 cell this one is 3.4Ah
- [x] add real time increment input to adjust
- [x] will determine max pan/tilt ranges
- [x] add wrapper to servo calls in Arduino that checks against max pos
  - printing out write degrees is a good idea before actually talkign to servos turns out
    - sent in 5557 (deg) haha
- [ ] create first polling/measurement set that runs from web all the way down
- [ ] plot 3d points in webgl (may be tough have watched some videos, skimmed MDN tutorial)
- at this time I am super burnt so we'll see, I won't give up till I'm crying or something happens
- crap did a download for VS Code/suggested after opening ino file and now touchpad/keyboard doesn't work ha
- this thing is trash in the long run, does not reposition, no position callback(encoder), cross language calls... ehh
- hit a wall delay in dynamic loop is ignored so sweep doesn't work
- guhh still stuck, monkey brain me trying to pry the end of a battery, so it starts smoking/getting warm as the walls are crushed/making contact. I got lucky it didn't get worst, but I commemorate this project to the 18650 which I had to drain, send back to the underverse.
- wow... that was a time sync... dumb dumb dumb. So you're not supposed to call delay and serial and shit inside a handler for i2c... I think shared clocks or something... anyway I have to refactor my code then I am closer to getting the 3d coordinates and plotting them in webgl. After that bridging OpenCV as the primary "brain/driver" in conjunction with the physical measurements to generate essentially a slower/more piece of crap real time map from an RGBD camera... but... it's on a Pi Zero(kinda).
- so I kinda failed... I know what I have to do, have to rework the code so the events are flags, will look at [this i2c guide](https://forum.arduino.cc/index.php?topic=683181) so I can get data back from Arduino on demand if I need to

### 11/01/2020
- [x] try out node i2c
  - see if it works
    - stop systemd code
    - try node i2c examples, check serial monitor
      - had to add new lines to stuff
      - doesn't work... write runs, Arduino receives nothing, error callback happens but says null
      - did have problems with the gcc install stuff(paths/package don't exist)
  - try to use it with websocket so Arduino response goes back up to web interface
- [ ] other alternatives
  - get websocket to work in Python, issue is Python version mixing
- well... I think I'm done with messing around with that, I still have not gotten the hard part, there may be a minor disconnect between servo motion and reading sensor data but I can just do batch sweeping/waiting/assumptions. I still need to get to the actual hard parts of this project eg. the basic 3d mapping from image/physical sensor data sampling
- thought about using a "signal" wire for events, it would be get a start/end pulse from Arduino and read by the pi through ADC, but it would introduce a lot of complexity.
  - main reason may not be worth it is the servos don't have tracking so can only assume they're done moving
  - still having an end signal come from Arduino is something
- [ ] get panning points
  - add pan code
  - do intermittent sampling, issue is syncing commands between Arduino and Python without a bridge

### 10/29/2020
- ### web interface
  - [ ] get feedback from Arduino after servos move
    - just echoes back command, front end uses to decide if next commands can go
    - just occurred to me, I need to be continuously listening to the Pi i2c to get anything back from the Arduino
    - which more than likely means some kind of thread and regarding communication between websocket/web interface...
      - probably have to write the socket in python instead vs. node, then the i2c listener thread can be started and ping the websocket that's running in python
      - no need to figure out how to communicate between python/node in real  time
      - so... when reading i2c the servos twitch... looks like it's a known problem, had a thought. I can just read out variables stored in Arduino by calling it(down send i2c)
    
  - [ ] trigger camera and display photo
  - [ ] get measurements from us and lidar by button click

### 10/27/2020
- ### web interface
  - [x] basic layout
  - [x] add basic servo control input
      - arrows and display of value
  - [x] add pi online status
      - [x] make this not hardcoded, possibly scannable by front end
  - [x] add websocket connected status
- ### pi
  - [x] setup basic node websocket
  - [x] send controls to arduino by system calls to python scripts
- ### arduino
  - [x] make basic servo state manager
  - [x] add accept capability to command servo from i2c and set state

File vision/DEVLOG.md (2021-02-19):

### Vision steps
The vision process boils down to using find contours after applying HSV ranges to look at. The HSV ranges are from the light (H, 1D histogram) and SV values from 2D histogram(color)
- take image
- perform 1D histogram to get light range (V)
- perform 2D histogram to get color range (H,S)
- apply mask over image for contour finding
- find contours and based on threshold(size of object/square) return possible obstacles
- sensor bed gets distances of the obstacles
- store into world coordinate system running in thread to update local map
- decide which way robot goes

- calibrate camera with horizon
- if boxes/boundaries are floating in midair, extend them downwards... unless height or sweep determines nothing under them

### Notes
- prioritize finding/scanning of nearest objects from an initial depth probe

- scanning process
  - [ ] do sensor sweep
    - anything in the way?
      - [ ] send command down from web(manual testing)
        - unfortunately no feedback from servo so just have to do some stepped sampling and  match pulses like us sensor
          concern is how fine(angle steps), since the farther away the larger the horizontal/vertical distances
  - take image
  - apply histograms/get bounds
  - point sensor bed to get measurements, hopefully hit targets
  - report to internal world coordinate system and to ThreeJS web interface

### 02/18/2021
Only tears today...

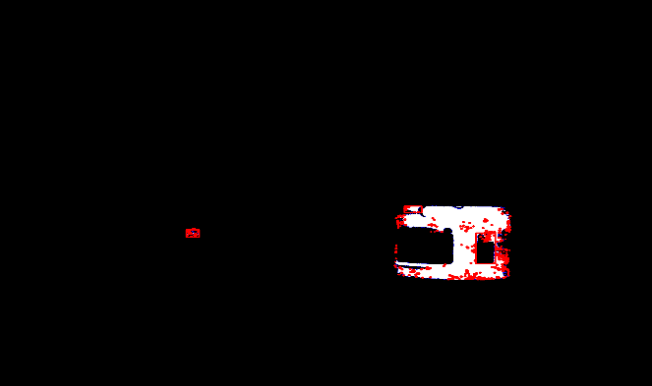
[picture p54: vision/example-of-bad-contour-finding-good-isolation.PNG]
bad contour obvious object


So above you can see that I isolated this red coffee container and while it is isolated pretty well the contours could not find it/have a big enough bounding rectangle.

So I need some alternative to finding contours where I can do a cluster finding like this. I saw some good stuff like [this one](https://stackoverflow.com/questions/17157296/detecting-clusters-of-white-pixels-in-an-image-using-opencv). Talked about erosion and dilation... anyway I frantically tried to do stuff but got nowhere... this is a tough one I'm not a great math guy.

Almost seems like I need to check both sides eg. in the case of lots of bright light, high density pixels/map the dark areas(referring to second image below) and use the clustering technique.
### 02/17/2021
Starting to work on histogram2d which finds H and S values for the mask.
Seems like need to look for clusters/get some general rules down eg. closer to 0 for S/x-axis means lighter color.
May need better sample images that have obvious color groups.

Lol so I ping a friend of mine who's really good at math and I'm like I'm trying to do this (screenshot below) and then he dumps this out into a text message lmao crazy. So yeah I gotta learn/see if I can use k-means.

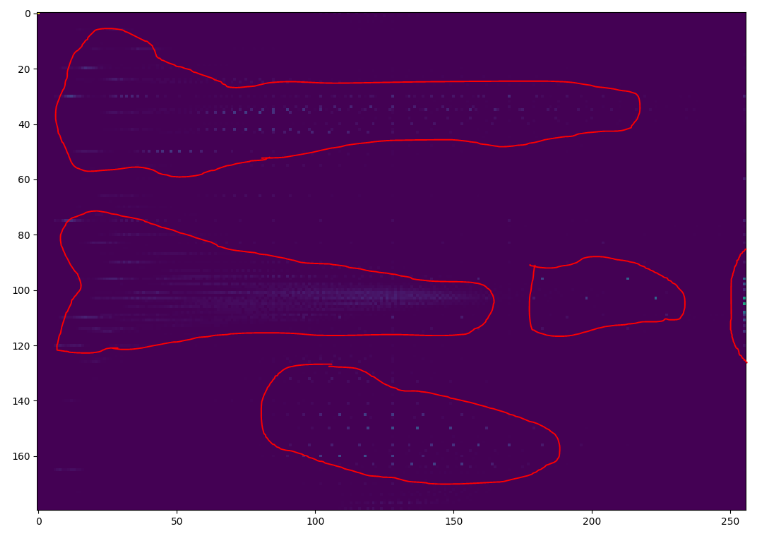
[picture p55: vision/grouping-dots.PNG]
grouping


> I have some scripts that do something like this. The technique is called "k-means". It's actually a pretty simple script, you may be able to write it yourself without much guidance. It doesnt draw boundary curves. It uses a number of "seed" points to determine which points are closest together (in groups). Here's the basics.
> 1) determine the number of groups to form (e.g. 4 groups). This is your k value. K=4
> 2) seed k=4 points randomly in your design space. If the x and y axes are both 0-256, then give each seed point a random (x, y) coordinate.
> 3) Now you iterate for some large number of iterations (e.g. 100). At each step in tje iteration, calculate the euclidean distance from each sample point to each seed point. If you have 200 sample points and 4 seed points, you will calculate 800 distances. Distance = sqrt((x2-x1)^2 (y2-y1)^2). Then for each sample point, determine which seed point is closest. For 4 seed points, you will end up with 4 groups of points. (e.g., sample point 1 is closest to seed point 3. sample point 100 is closest to seed point 2.). Finally move each seed point to the average (x, y) of the sample points in it's group. (e.g. if there are 50 sample points closest to seed point 4, calculate the average (x, y) of those 50 sample points. That average is the new location of seed point 4 for the nexr iteration). Over time, tje seed points will move towards the centroids of each data set, and each group of sample
 points willbe sorted according to which point is nearest.

I added a more obvious color sampling image. The goal isn't to set values directly rather to write the algorithm that pulls them from the histograms and then ties in with a "loop" with the ToF sensors for "redundancy".

ehh... the k-means or other grouping ways will be interesting. I still don't know what the colors mean on 2D Histogram time to crowd source(look like a dumbass online).

There's probably something stupid/obvious I'm blissfully unaware of that makes this entire approach stupid but I'm going to finish thing. It's a neat little project and I will transfer the knowledge to my next project.

Yeah you can see below targetting the largest blob is not such a safe approach. Also these boxes are massive will see about reducing them. I know... if you had some kind of trained object detection system could run frame by frame (real time) vs. this single frame approach.

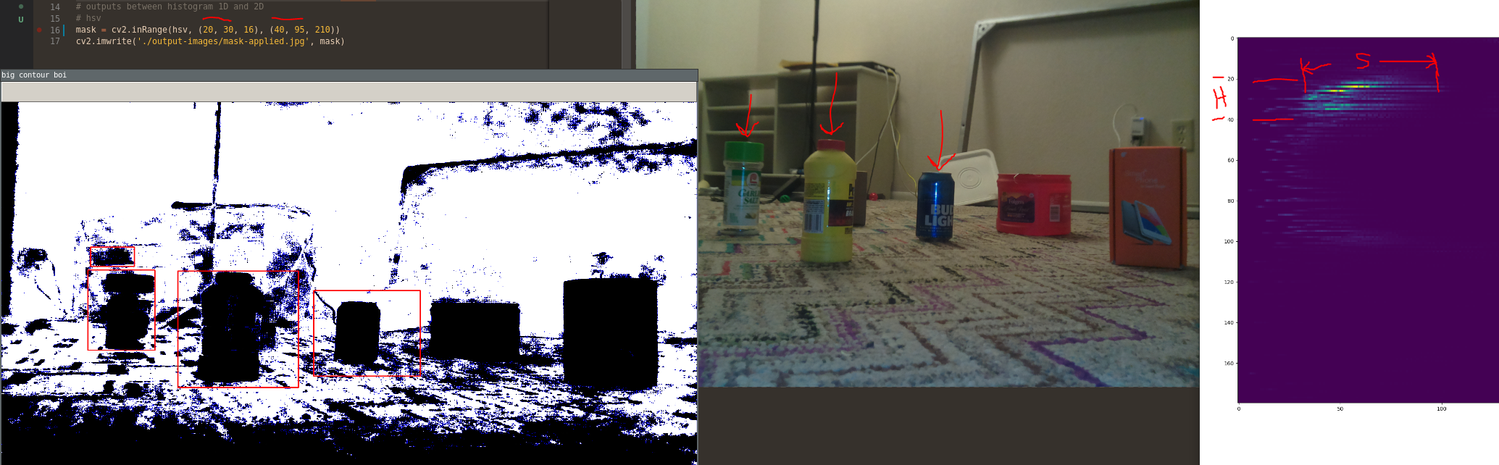
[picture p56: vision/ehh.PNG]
ehh


Not much better higher sq pixel area filter is better seems like. Thing to consider is square overlap.

So far my rotate color reference doesn't seem to match.

### 02/16/2021
Did get distracted with that readme not really anything new ego filling.
Aiming to put like 2 hours of silence work into this project since it's not trivial/I really need to focus/pay attention.

### 02/14/2021
Working on the plot value chunker
https://jsfiddle.net/qsw2co0x/18/

### 02/13/2021
Back on this project again finally... had to make a couple of bs personal todo-esk crud apps so I can feel good about my life.
I have to remember the steps.
This is pretty neat actually I have to consider if it's dark and then if so change the scanning methods eg. rely on ToF sensors more than vision.

I was trying to return sectioned x-ranges from histogram1D although the first sample image has a contiguous plot so I'm hoping the new images have broken up x ranges/groups on the plot so I can return the separated array of array start/stop pairs

### ~~12/24/2020~~ 12/25/2020
~~I'm not as "fresh" as I'd like to be, I had to deal with some stuff hours ago. I'm hoping I can still be productive.
Been up about 5 hours already and between now and then have eaten... I usually try not to eat/only partake in caffeine to be "pure" optimal~~

Well... scratch that, wasted that day, here I am now next day. Already ate though.

I did have a thought, I should be able to just re-use the panning code from the ultrasonic sensor for lidar, just change the sensor call.
Need to establish some boundaries too. Robot dimensions 8.5" x 10" x 11" these are upwardly approximated.
Overall nothing is square, minor irregularities here and there... ideally that's fine. The device adapts/recalibrates.
Camera height when mounted on robot platform: 8.5"
Sensor bed center point height: 5" 5/8"

You know... I don't want to do this it turns out haha. But I gotta finish it.

I'm gonna focus on coming up with some kind of sampling algorithm. The depth probing is a way to narrow down what to look for that matters.
Since as a human you can easily be like "there's an object, there's an object" etc... but camera/pixels no idea what's what.
Can just do boundary detection/find blobs of things.

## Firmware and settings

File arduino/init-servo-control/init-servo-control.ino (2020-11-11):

// The I2C part of this code is based on this tutorial:
// https://dronebotworkshop.com/i2c-arduino-raspberry-pi/
// laughably struggled with simple string split
// https://forum.arduino.cc/index.php?topic=155667.0

#include <Wire.h>
#include <Servo.h>

Servo tiltServo;
Servo panServo;

int panServoPos = 94;
int panMaxRange = 30;
int tiltServoPos = 89;
int tiltMaxRange = 30;

String mainCmd = "";
String secondParam = "";
String secondCmd = "";
String thirdCmd = "";
String fourthCmd = "";

bool isCmdProcessing = false;
bool isFullSweepCmd = false;
bool isFullSweepLoopProcessing = false;

// build out variables for full sweep
// this sucks but can't seem to just split the assembled string/char group from i2c
String fsPanMinRange = "";
String fsPanMaxRange = "";
String fsTiltMinRange = "";
String fsTiltMaxRange = "";
String fsIncrement = "";
String fsDelay = "";

void setup() {
  Serial.begin(9600);
  Wire.begin(0x8);
  Wire.onReceive(receiveEvent);
  panServo.attach(2);
  tiltServo.attach(3);
  panServo.write(panServoPos);
  tiltServo.write(tiltServoPos);
}

// makes sure max range not exceeded
void servoWrite(String servo, int pos) {
  if (servo == "pan") {
    if (pos <= (panServoPos + panMaxRange) || pos >= (panServoPos - panMaxRange)) {
      panServo.write(pos);
    }
  } else {
    if (pos <= (tiltServoPos + tiltMaxRange) || pos >= (tiltServoPos - tiltMaxRange)) {
      tiltServo.write(pos);
    }
  }

  isCmdProcessing = false;
}

// delayMs set to 0 due to base delay of 1s per servo motion
void sweep(String servo, int increment = 2, int delayMs = 1000, int min = 0, int max = 0) { // min max normally not passed in
  bool isPanServo = servo == "pan";
  int sweepMin = isPanServo ? (panServoPos - panMaxRange) : (tiltServoPos - tiltMaxRange); // 30 is a coincidence
  int sweepMax = isPanServo ? (panServoPos + panMaxRange) : (tiltServoPos + tiltMaxRange);

  if (min && max) {
    sweepMin = isPanServo ? (panServoPos - max) : (tiltServoPos - max);
    sweepMax = isPanServo ? (panServoPos + max) : (tiltServoPos + max);
  }

  // sign seems to be stripped
  for (int i = sweepMin; i <= sweepMax; i = i + increment) {
    isCmdProcessing = true;

    servoWrite(servo, i);

    if (i > sweepMax) {
      servoWrite(servo, i);
    }

    // timeLoop(millis(), delayMs);
    delay(delayMs);
  }

  isCmdProcessing = false;
}

// these do need better names, not just incremental commands
void resetI2cVariables() {
  mainCmd = "";
  secondParam = "";
  secondCmd = "";
  thirdCmd = "";
  fourthCmd = "";
  isFullSweepCmd = false;
  fsPanMinRange = "";
  fsPanMaxRange = "";
  fsTiltMinRange = "";
  fsTiltMaxRange = "";
  fsIncrement = "";
  fsDelay = "";
}

void receiveEvent(int bytes) {
  Serial.println("receive");
  if (isCmdProcessing || isFullSweepLoopProcessing) {
    return;
  }

  int loopCounter = 0;
  resetI2cVariables();

  // the reason these values are split is because
  // if I just join them into one big string, try to parse/access by array
  // the values aren't correct
  while (Wire.available()) {
    char c = Wire.read();

    if (loopCounter == 1) {
      mainCmd = c;
    }

    if (loopCounter == 2) {
      secondParam = c;

      if (mainCmd == "s" && secondParam == "_") {
        isFullSweepCmd = true;
      }
    }


    if (isFullSweepCmd) {
      // get extra params from cmd ex. s_p-020, 020_t-010, 030_1000
      if (loopCounter > 3 && loopCounter < 8) {
        fsPanMinRange += c;
      }

      if (loopCounter > 8 && loopCounter < 12) {
        fsPanMaxRange += c;
      }

      if (loopCounter > 13 && loopCounter < 18) {
        fsTiltMinRange += c;
      }

      if (loopCounter > 18 && loopCounter < 22) {
        fsTiltMaxRange += c;
      }

      if (loopCounter > 23 && loopCounter < 27) {
        fsIncrement += c;
      }

      if (loopCounter > 27) {
        fsDelay += c;
      }
    } else {
      if (loopCounter > 1 and loopCounter < 5) { // eg. p179 or t179
        secondCmd += c; // 001 for increment 1
      }

      if (loopCounter == 5) { // eg. s179t || s179p
        thirdCmd = c;
      }

      if (loopCounter > 5 && loopCounter <= 9) { // eg. s179t1000... what about 0.5 or 10000 (10 seconds)
        fourthCmd += c;
      }
    }

    loopCounter++;
  }
}

void fullSweep() {
  // sample cmd: s_p-010,010_t-010,010_i010_500
  // means p range is -10 to 10 deg, tilt is -10 to 10 deg, increment is 10 meaning -10, 0, 10 and servo delay is 500
  int fsIncrementInt = fsIncrement.toInt();

  for (int i = fsTiltMinRange.toInt(); i <= fsTiltMaxRange.toInt(); i = i + fsIncrementInt) {
    servoWrite("tilt", tiltServoPos + i);
    delay(fsIncrementInt);
    sweep("pan", fsIncrement.toInt(), fsDelay.toInt(), fsPanMinRange.toInt(), fsPanMaxRange.toInt()); // ehh all this type conversion
    delay(fsIncrementInt);
    // could watch current draw on servo to see when it stops moving(drop)
  }
}

void recenterServos() {
  isCmdProcessing = true;
  servoWrite("pan", panServoPos);
  isCmdProcessing = true;
  servoWrite("tilt", tiltServoPos);
}

void loop() {
  // this is all ugly but still in prototype stage
  if (mainCmd == "p") {
    isCmdProcessing = true;
    servoWrite("pan", secondCmd.toInt());
    delay(1000); // no position feedback
  }
  
  if (mainCmd == "t") {
    isCmdProcessing = true;
    servoWrite("tilt", secondCmd.toInt());
    delay(1000); // no position feedback
  }

  if (mainCmd == "s") {
    if (secondParam != "") { // wait till determine what command
      if (isFullSweepCmd) {
        isFullSweepLoopProcessing = true;
        fullSweep();
        recenterServos();
        isFullSweepLoopProcessing = false;
      } else {
        if (thirdCmd == "p") {
          sweep("pan", secondCmd.toInt(), fourthCmd.toInt());
        } else {
          sweep("tilt", secondCmd.toInt(), fourthCmd.toInt());
        }
        recenterServos();
      }
    }
  }

  if (!isCmdProcessing && !isFullSweepLoopProcessing) {
    resetI2cVariables();
  }

  delay(100);
}

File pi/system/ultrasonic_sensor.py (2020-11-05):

# sensor HC-SR04
# code sourced here
# https://thepihut.com/blogs/raspberry-pi-tutorials/hc-sr04-ultrasonic-range-sensor-on-the-raspberry-pi

import RPi.GPIO as GPIO
import time

class UltrasonicSensor:
  def __init__(self):
    self.unit = 'in'
    GPIO.setwarnings(False)
    GPIO.setmode(GPIO.BCM)
  
  # supports cm or in
  def set_unit(self, unit):
    if (unit == 'in' or unit == 'cm'):
      self.unit = unit
    else:
      raise ValueError('wrong unit')

  def get_measurement(self):
    GPIO.setmode(GPIO.BCM)
    TRIG = 27
    ECHO = 22

    GPIO.setup(TRIG, GPIO.OUT)
    GPIO.setup(ECHO, GPIO.IN)

    GPIO.output(TRIG, False)
    time.sleep(0.05)

    GPIO.output(TRIG, True)
    time.sleep(0.00001)
    GPIO.output(TRIG, False)

    while GPIO.input(ECHO) == 0:
      pulse_start = time.time()

    while GPIO.input(ECHO) == 1:
      pulse_end = time.time()

    pulse_duration = pulse_end - pulse_start

    if (self.unit == 'in'):
      distance = pulse_duration * 17150 * 0.3937
    else:
      distance = pulse_duration * 17150

    distance = round(distance, 2)
    GPIO.cleanup()

    return distance

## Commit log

2020-10-28 basic pi server and socket
2020-10-28 add method to call Arduino code by i2c from python
2020-10-28 working python to Arduino code
2020-10-28 working python arg to arduino
2020-10-28 working socket to python call
2020-10-29 add the 3d sketchup files
    [2-cell-li-ion.skp, 5mp-camera.skp, 5v-ubec.skp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]
2020-10-30 tried to get data from Arduino to pi, failed
    [init-servo-control.ino]
2020-10-30 revert arduino code to previous
    [init-servo-control.ino]
2020-11-03 working on servo guards and initial sweep code for measurement scanning
2020-11-03 working sample code, not sure why delay not working
2020-11-03 working on servo sweep code
2020-11-03 updated arduino code for dynamice sweep
2020-11-05 updated servo centering and correct angle travel
    [init-servo-control.ino]
2020-11-07 was working on sensor offset for rotation
2020-11-11 current sweep code
2020-11-11 current code not quite where I wanted to be
2020-11-17 add note about sensor offset, still missing the function
2020-11-26 save for now, going to change power distribution
2020-12-19 update readme before putting in current OpenCV files
2020-12-19 add current OpenCV code since 2 weeks ago
